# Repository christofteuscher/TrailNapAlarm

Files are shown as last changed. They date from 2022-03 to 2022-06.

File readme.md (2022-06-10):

# Trail Nap Alarm
## Overview
Abstract block diagram
### Introduction and problem statement:
Ultra marathon runners, i.e., runners who run distances longer than a marathon, often do “trail naps,” i.e., they simply lay down on the trail and power nap for 5-10min. When it’s cold, one wakes up after a short period of time, but when it’s warm(er), it’s likely that the runner will sleep longerthan they want. Setting an alarm is tedious, time-consuming, and the alarm may not be heard. Also,sometimes it takes a few minutes to fall asleep, so estimating the wake-up time is hard and the resulting sleep time is rarely ideal.
The goal of this project is to build a device that monitors a runner’s sleep and wakes them up aftersleep stage N1, before they fall into a REM sleep pattern. Non-REM sleep has 3 stages ([Source:](https://www.uofmhealth.org/health-library/hw48331)):
* **Stage** N1 occurs right after you fall asleep and is very short (usually less than 10 minutes).It involves light sleep from which you can be awakened easily.
* **Stage N2** lasts from about 30 to 60 minutes. During this stage, your muscles become more relaxed and you may begin to have slow-wave (delta) brain activity.
* **Stage N3** is deep sleep and lasts about 20 to 40 minutes. During this stage, delta brain activity increases and a person may have some body movements. It is very hard to wake up someone in stage N3.

### Specific project goals
1. Build a sensor system that allows to detect the different sleep patterns. The sensor system needs to be small, simple, non-invasive, and ultra-low power. E.g., an armband, electrodes embedded in a hat, etc.
2. Build a system that reliably wakes up a person. E.g., a combination of sound, vibration, etc. That part must also be small, simple, non-invasive, and ultra-low power.
3. An integration of these two sub-components into a fully functional system. Cables should be avoided. If communication between sub-systems is necessary, that should rely on Bluetooth or other protocols.
4. The system must be battery-powered. The batteries should last for at least 3 days (72 hours). The batteries should be rechargeable with a USB cable.
5. The overall system must be small, non-invasive, light, water-proof, easy to use, and have no on-off or other switches.

## Project status
This project is unfinished and serves only as a proof-of-concept. The intention is for the final product to be as passively-operational as possible - meaning that all the user has to do is turn it on and wear it during a nap, then turn it off when they are woken up. For further development, please refer to the [documentation in the wiki for this repository](https://github.com/cteusche/TrailNapAlarm/wiki).

To start developing this project:
1. Clone this repository
2. Install [conda mini-forge](https://github.com/conda-forge/miniforge) package handler.
3. In the terminal, go to the home directory of this repo and run the command 
   
   `conda env create -f environment.yml` 
   
   to set up a new conda environment and install the required python libraries into it.

## Directory structure
* [src](https://github.com/cteusche/TrailNapAlarm/tree/main/src)
    * Source code files belong here
* [tools](https://github.com/cteusche/TrailNapAlarm/tree/main/tools)
    * Tools like Makefile and other scripts belong here
* [docs](https://github.com/cteusche/TrailNapAlarm/tree/main/docs)
    * Documentation files belong here
* [dep](https://github.com/cteusche/TrailNapAlarm/tree/main/dep)
    * Dependencies belong here
* [res](https://github.com/cteusche/TrailNapAlarm/tree/main/res)
    * Resource files belong here

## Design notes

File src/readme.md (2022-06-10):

# Description of program files and their context

Core application function is handled by record.py, analysis.py, and buzzer.py.

Python programs are connected via piping to form the core function.

## record.py

Sample and record brainwave data from ADC. Send data to analysis.py for processing. 

```
Usage: record.py [options]

Record sampled EEG data.

Options:
  -h, --help            show this help message and exit
  --wav                 Save epoch as wav file format.
  --csv                 Save epoch as csv file format. (Not Implemented)
  -s EPOCH_SECONDS, --seconds=EPOCH_SECONDS
                        Number of seconds in each epoch.
  -n NUM_EPOCHS, --num_epochs=NUM_EPOCHS
                        Number of epochs to record.
  -v, --view_samples    Display samples at a reduced rate.
```

Command line options exist for testing and debug. We can set epoch size and the number of epochs to record as well as enable viewing scaled sample values directly from command line.

We usually run with `python3 record.py --wav` and pipe output into the `analysis.py` program for processing.

### ADS1115 Configuration

We configure the ADS1115 to read data in the ±1.024 range. We sample data on the AIN2 pin with AIN3 as the zero reference. The configuration string `0b0_011_011_0_101_00000` is sent over I2C to initialize the continuous sampling. The device is configured to send interrupts when the data is ready.

We setup an interrupt service routine to watch for interrupts on the device.

### Checking the Timing of the ADS1115

Readings were taking a longer then expected time for the configured Samples Per Second (SPS) value. Used the oscilloscope to check the timing of the interrupt pulses. We noticed the rate was not correct. Checked generated rate by scope for 250 SPS and measured 243 Hz. Added code to time elapsed time over the span of a 30s epoch. We have the optoion to correct the recored rate based on the first measured samplerate.

*Timing is still a bit off. Perhaps we look into device driven data rate again.*

## analysis.py

This program implements the YASA sleep staging algorithm and determines when to wake the user based on a specified N2 epoch count threshold. It takes a file path as a command line argument and concatenates it to an ongoing array of the current sleep session's EEG time series data, with a corresponding sample rate. Once the array of data has surpassed the minimum analysis duration of 5 minutes, as well as the minimum sleep duration specified, it creates a SleepStaging instance to determine the predicted sleep stages for each epoch of recorded data. It repeats this each time it recieves a new filepath, which is every 30 seconds. Once the previous conditions are met, and an N2 threshold is surpassed or the maximum sleep duration has passed, the program activates the alarm system.

User preferences are defined at the top of this file:

minNapMinutes: integer, the minimum number of minutes that the nap should last. The program will not start counting N2 stages detected before this time. This is especially helpful at the start of the program, when predicted sleep stages can be less reliable, so we don't accidentally wake the user too soon.

maxNapMinutes: integer, the maximum number of minutes that the nap should last. As a default, in case the N2 threshold count is not met, the program will wake the user after this number of minutes has elapsed.

minN2epochs: integer, the N2 threshold count. The program will wake the user after this many epochs (30 second segments) have been predicted as stage N2 sleep.

## buzzer.py

This module contains code to play notificaitons on the buzzer. Commands are piped in line by line and the program reacts. Internally the program uses signals to time tones.

- 'READY' plays when the device is connected and ready to start recording.
- 'WAKEUP' command plays the alarm tone to awake the user.
- 'STOP' stops any playing sounds.
- 'TEST' plays a test signal to test the range of values.

The program watches carefully for signals to stop playing a sound if anything goes wrong or the program is stopped.

## buildRaw.py

This module contains definitions for functions which translate different data formats into the MNE "raw" object type. The YASA SleepStaging class takes a raw object type. The current formats are .npz, .wav, and array with a corresponding sample rate.

buildRawFromNpz(fs, filepath)

    fs:         integer, sample rate
    filepath:   string, path to the file

buildRawFromWav(filepath)

    filepath:   string, path to the file

buildRawFromArray(fs, array)

    fs:         integer, sample rate
    filepath:   string, path to the file

## dataSetup.py

This program is used entirely for testing and development, and is not implemented in the functioning of the device itself. It was written as a sandboxing tool for reading different recording file times, from various datasets and devices, and cutting them up into 30 second .wav files to simulate data being fed to analysis.py

## read.py

A test file used in conjunction with send.py. This program is piped a command and a file name from send.py and follows the command sent.

## send.py

A test file that creates a list of files in a directory, then sends the path name to analysis.py one at a time to test the functioning of piping recording file names to the analysis program.

## test.py

Uses functions defined in testPlots.py to make certain plots and analyses on datasets gathered by the team. Given a directory with a .wav file of sleep data, it returns the predicted sleep stages of that dataset and makes a plot of a specified epoch with any detected sleep spindles highlighted.

## testPlots.py

This module contains definitions for functions used in test.py.

spindlePlot(fs,indata,epochNum,title,window)

    fs:         integer, specifies the sample rate of the data
    indata:     array of real-valued data to be plotted
    epochNum:   integer, which 30 second segment to display
    title:      string, the predicted sleep stage of the plotted epoch
    window:     integer, length in samples of the moving average window to smooth plot output (doesn't affect analysis)

The other functions in testPlots.py weren't used in this project.

## test_buzzer.py

This module contains initial code to verify that the buzzer is working.

## test_interrupt.py

This module contains initial code to verify interrupt processing is working.

## Unused/Retired Files

We archive unused files in the `_unused` folder.

-  `btnWake.py` Poll for a change on an analog read pin as a makeshift interrupt. Used for initial i2c bringup. Owner: Michael
- `collectData_0.1.py` Initial pass at i2c code without interurpt. Timing was a problem even here. Owner: Michael
- `collectData_0.2.py` Version 2 of i2c code. This eventually formed into `record.py`. Owner: Julia
- `every.py` Attempt at abstracting away precise timing with python. Retired for interrupt based timing from ADC source. Could be useful for future work. Owner: Julia
- `pollData.py` Initial implementation of i2c code. Owner: Michael
- `pollStart.py` Initial implementation of i2c code. Owner: Michael

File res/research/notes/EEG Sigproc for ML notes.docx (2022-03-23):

Also, there are other rhythms introduced by researchers such as:

e) Phi (φ) rhythm (less than 4 Hz) occurring within two seconds of eye closure. The phi rhythm was introduced by Daly [3].

f) The kappa (κ) rhythm, which is an anterior temporal alpha-like rhythm and it is believed to be the result of discrete lateral oscillations of the eyeballs and is considered to be an artefact signal.

g) The sleep spindles (also called sigma [σ] activity) within the 11–15 Hz frequency range.

h) Tau (τ) rhythm which represents the alpha activity in the temporal region.

i) Eyelid flutter with closed eyes which gives rise to frontal artefacts in the alpha band.

j) Chi rhythm is a mu-like activity believed to be a specific rolandic pattern of 11–17 Hz.

This wave has been observed during the course of Hatha Yoga exercises [8].

k) Lambda (λ) waves are most prominent in waking patients, although they are not very common. They are sharp transients occurring over the occipital region of the head of walking subjects during visual exploration. They are positive and time-locked to sac-

cadic eye movement with varying amplitude, generally below 90 μV [9].

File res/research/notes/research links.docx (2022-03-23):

### Existing research on EEG data

You might have to be logged in through the PSU library portal to access some of the IEEE datasets.

Basic introduction to EEGs and brainwaves

https://www.medicine.mcgill.ca/physio/vlab/biomed_signals/eeg_n.htm

Sleep Stages and Scoring Technique

http://www.fmed.edu.uy/sites/www.labsueno.fmed.edu.uy/files/9.Diagnostico-polisomnogr%C3%A1fico.pdf

Normal Sleep EEG

https://emedicine.medscape.com/article/1140322-overview#a1

Visualization of Whole-Night Sleep EEG From 2-Channel Mobile Recording Device Reveals Distinct Deep Sleep Stages with Differential Electrodermal Activity

https://www.frontiersin.org/articles/10.3389/fnhum.2016.00605/full

Analysis of Multichannel EEG Patterns During Human Sleep: A Novel Approach

https://www.frontiersin.org/articles/10.3389/fnhum.2018.00121/full

Electroencephalography: An Introductory Text and Atlas of Normal and Abnormal Findings in Adults, Children, and Infants

https://www.ncbi.nlm.nih.gov/books/NBK390354/pdf/Bookshelf_NBK390354.pdf

Comparison of Smoothing Filters in Analysis of EEG Data for the Medical Diagnostics Purposes

https://www.ncbi.nlm.nih.gov/pmc/articles/PMC7038754/

EEG-Datasets

https://github.com/meagmohit/EEG-Datasets

DATASETS FOR "GRAPH ANALYSIS OF SINGLE-CHANNEL SLEEP STAGE EEG WITH DIFFERENT ELECTRODE PLACEMENTS"

https://ieee-dataport.org/documents/datasets-graph-analysis-single-channel-sleep-stage-eeg-different-electrode-placements

ACTIVITIES OF DAILY LIVINGS USING A PORTABLE EEG HEADSET

https://ieee-dataport.org/open-access/activities-daily-livings-using-portable-eeg-headset

DIY EEG (and ECG) Circuit

https://www.instructables.com/DIY-EEG-and-ECG-Circuit/

Final Project: DIY EEG EEG: Cheap and Small Fall 2015

http://fab.cba.mit.edu/classes/863.15/section.Harvard/people/Ricker/htm/Final_Project.html

She links to this:

Homebrew Do-it-yourself EEG, EKG, and EMG

https://sites.google.com/site/chipstein/home-page

(good idea… but some broken links)

Make an EEG Beanie That Reads Your Mind

https://makezine.com/projects/mind-reading-beanie/

The Introductory Guide to EEG

(Electroencephalography)

https://www.emotiv.com/eeg-guide/

(interesting idea using the ear to hold electrodes)

Unobtrusive ambulatory EEG using a smartphone and flexible printed electrodes around the ear

https://www.nature.com/articles/srep16743

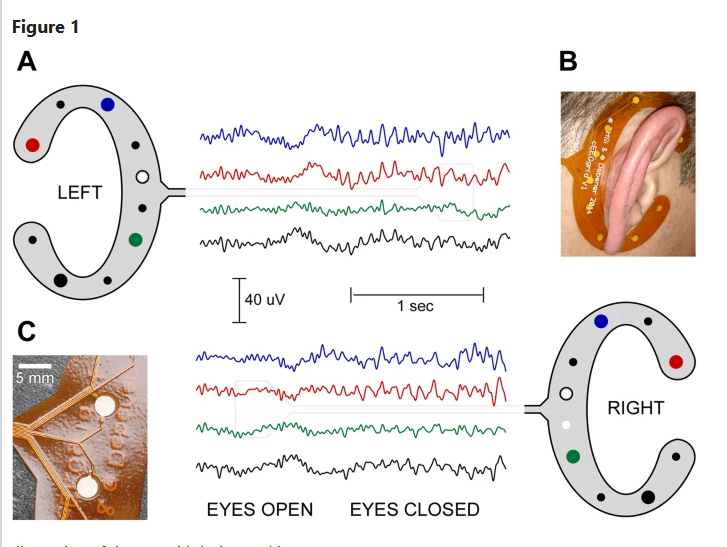
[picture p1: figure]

(I like this one… But there are broken links. Maybe it's a dead project)

Welcome to the OpenEEG project

http://openeeg.sourceforge.net/doc/index.html

EEG probe electrode amplifier design

https://www.researchgate.net/publication/50398093_Portable_cost-effective_EEG_data_acquisition_system

https://www.sleepfoundation.org/stages-of-sleep

TinySleepNet - open source deep learning model for sleep scoring (python)

https://github.com/akaraspt/tinysleepnet

https://ieeexplore.ieee.org/document/9176741

Using Two EEG electrodes on forehead

https://pubmed.ncbi.nlm.nih.gov/24313630/

EEG Montage configurations (not entirely applicable but useful knowledge)
https://www.learningeeg.com/montages-and-technical-components

AASM Recommendations for EEG Electrode Placement in Polysomnography: Impact on Sleep and Cortical Arousal Scoring
https://academic.oup.com/sleep/article/34/1/73/2433800?login=false

Main features of the EEG amplifier explained

https://www.bitbrain.com/blog/eeg-amplifier

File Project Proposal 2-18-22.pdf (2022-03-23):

# AUTOMATIC SLEEP MONITOR AND TRAIL NAP ALARM

Team 23:
Nick Porter, Luke Hoskam, Dang Nguyen, Julia Filipchuk, Michael Weston Industry Sponsor: Dr. Christof Teuscher Faculty Advisor: Dr. Donald Duncan

## Executive Summary

The purpose of this project is to design and prototype a wearable device which can monitor the wearer’s stages of sleep and wake them from a short (10-20 minute) nap after N1 stage sleep, but before REM. This requirement puts the optimal time of awakening during the N2 stage of sleep.
The device fits within a lightweight and unobtrusive headband that passively monitors a person’s heart-rate and EEG while worn. It works without user interaction. The device continuously monitors via two electrode probes within the headband on the forehead at locations FP1 and FP2 [1] and a reference probe connected to the earlobe. From this location, both heart rate and EEG signals can be detected using the same probes.
These signals will be passed to a microcontroller within the headband to process and detect when the user is resting, and what stage of sleep they are currently in. It will allow the user to sleep for roughly 15 minutes (starting from N1 stage detection, but including at least 3 minutes of stage N2), but no longer than 30 minutes. The user will then be awoken using a small vibrating motor and sound. We explain the reasoning behind these choices in the following sections.

## Background

The design of this device will rely on existing research in biometrics, automated sleep research, and digital signal processing (DSP) libraries for small embedded devices.
Sites FP1 and FP2 were chosen since they are optimal for detecting heart rate, as well as sleep spindles and k-complexes during N2 stage [1].
Research in sleep shows that 20 minute naps are more effective for performance than longer naps, and that sleep inertia occurs after 30 minutes. It also shows that stage 2 has a significant effect on restorative effects, and that at least 3 minutes of stage 2 sleep can be beneficial to performance recovery [2].
NREM sleep is divided into 4 sleep stages, which progress from drowsiness into deep sleep before switching into REM sleep. These stages are accompanied by a series of frequency changes through dominant Alpha (8 - 12 Hz), Beta (12 - 38Hz), Theta (3 - 8Hz), and Delta (0.5 -3Hz) waves. Stage 1 NREM sleep is best characterized by being easy to wake from and a reduction of Alpha waves in adults. As drowsiness deepens, the slow wave activity grows. At the transition between stages 1 and 2, the phenomena of vertex waves and sleep spindles will occur. At stage 2, eye movement will cease, low frequencies will dominate, and K-complex components will be present. Further stages 3 and 4 will be denoted by the increasing presence of Delta waves.
This project focuses on using EEG signals for sleep stage detection, but there are new developments in using only heart-rate monitoring for this purpose. One such study provides a method for sleep stage detection using just a heart rate signal, with a theoretical recognition rate for N2 stage of 90% [3]. We are not pursuing this method since there are less software resources available. Heart rate nonetheless is still useful for indicating the initial transition from active movement to a resting state.

## Product Design Specification

### Concept of operations / User stories

Long distance trail runners have to fit short periods of rest in a multiple-day endurance race. Sleep is critical to recovery for runners who compete in races that last for days. In order to get enough sleep and not lose your position in a race, competitors have to time their sleep to the minute. They often have to take short (10-20 minute) naps along the trail. Brief naps have a tendency to leave a person groggy, especially if they are awoken during certain sleep stages, and every person’s sleep cycles are slightly different.
The Trail Nap sleep alarm addresses this issue by monitoring a person’s biometrics and detecting when they are in different stages of sleep in order to awaken the wearer after a duration that leaves them less groggy than if they hadn’t used this device. That duration depends on how quickly the user falls asleep, and how much time they spend on each sleep stage. The device works passively, so the user does not have to take the time to set an alarm, or even engage it when they decide to stop for a nap.

### Stakeholders

Dr. Christof Teuscher is a professor at PSU, director of the Teuscher Lab, and an avid trail runner. He is the industry sponsor for this project, and created the initial project proposal we are basing this project on. The team itself is also a stakeholder in this project, as the main researchers and developers for the final prototype.
We specifically designed this system for endurance trail runners. It will be used by our industry sponsor, but we will also make the designs open-source and available to anyone who wishes to build it using our documentation. There are no current plans for commercialization.

### Requirements

As quoted from our industry sponsor’s project proposal: “The goal of this project is to build a device that monitors a runner’s sleep and wakes them up after sleep stage N1, before they fall into a REM sleep pattern.” This goal, along with the expectation that a nap will be 15-20 minutes (and no longer than 30 minutes) means that the user will reliably be woken up during stage 2 sleep (N2).

Further requirements include:
- Must detect different sleep stages.
- Must reliably wake person after 3 minutes of stage 2 (N2) sleep, but before 30 minutes of sleep
- Must be small, non-invasive, light, easy to use
- Should have no on-off or other switches
- We might have a power switch to shut off when not worn
- Should be water-proof
- Must be “ultra-low power”
- Must be battery powered
- Batteries should last 3 days
- Should be rechargeable over USB
- May be two devices which connect wirelessly

### Specifications

- PocketBeagle with two 3000mAh LiPo batteries will yield ~1200 hours in idle and ~24 hours stressed.
- PocketBeagle integrated LiPo battery regulation
- Target weight limit: ~4 ounces. No more than 0.5 lbs.

### Deliverables

- A functional prototype
- Code (on github), nicely documented
- Project proposal
- Weekly Progress Reports to our faculty advisor, as well as to our industry sponsor if they desire.
- Final report
- ECE capstone session poster
- Any other documentation or activities (presentations) the faculty advisor requires
- Electrical CAD: Schematics and board layouts, including output files (Gerbers, PDFs, etc)
- Mechanical CAD: enclosures, mechanisms, including output files (STLs, PDFs, etc)
- Bill of materials and pricing
- Short user manuals documenting how to use the device and software
- Version control, including checked in previous revisions of the design (via git repo)

### Initial product designs

Hardware Architecture

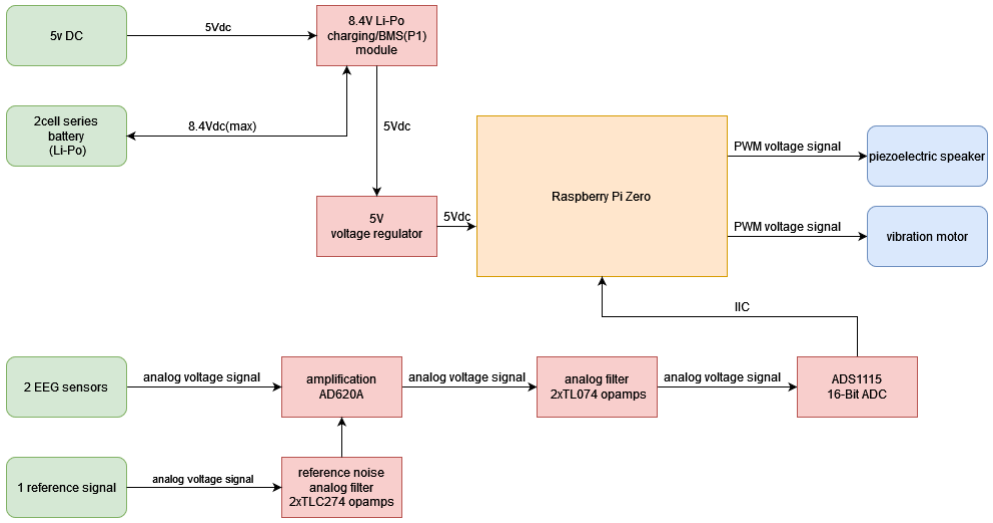
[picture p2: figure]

Fig. 1: L1 diagram of Nap Monitor (the Pi-zero has been replaced with a PocketBeagle)

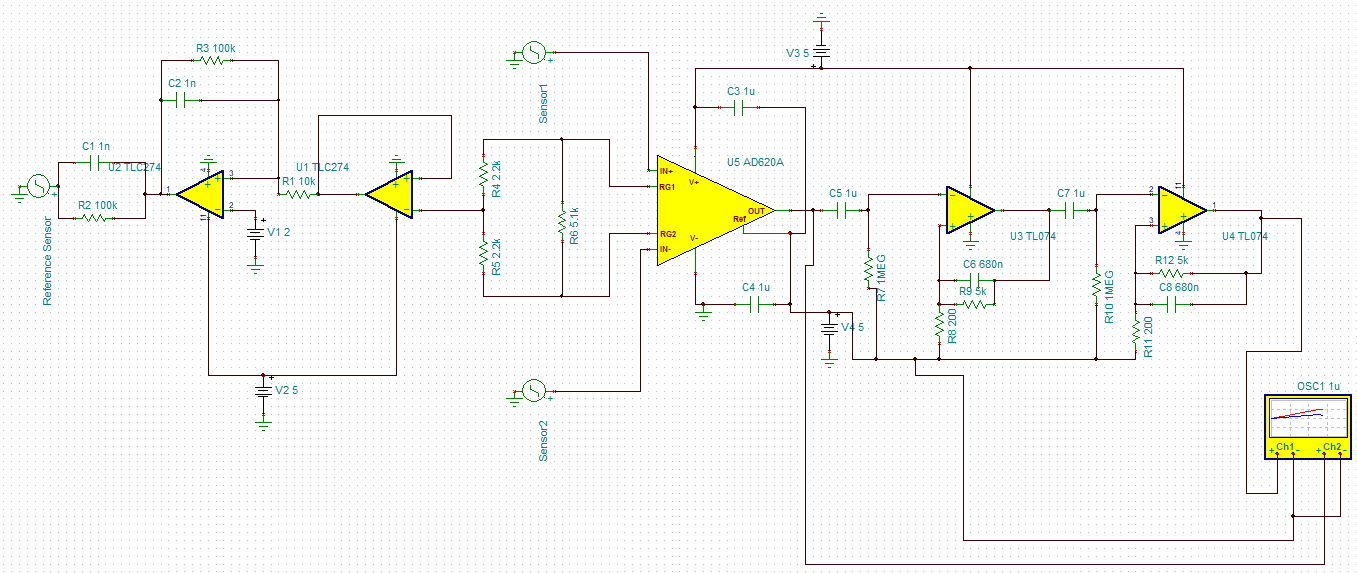
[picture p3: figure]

Fig. 2: Circuit design for a dual EEG probe amplification and analog LPF based on the paper, Portable cost-effective EEG data acquisition system [4]

The above amplification system allows for common voltages between the two electrodes to be canceled out, thus reducing the noise levels from movement. The PocketBeagle is powered at 5v and can provide power to the amplification circuit. The design of the amplification system includes a method of using a virtual ground for +/- rails.

Microcontroller: Pi-Zero PocketBeagle
- Balancing low power and size with processing capacity
- Cheap, accessible
- Easily configurable with peripheral devices

The basic signal chain will go like this: low-voltage noisy signals are amplified, then some rough analog low-pass filtering will occur to pass the analog signal into the ADS1115 ADC. The digital signal will then be passed to the processor via I

2C.

Software Architecture
We intend to use the Python MNE library (https://mne.tools) for developing digital filters and event detection methods. This library, along with the available resources for using Python on a microcontroller, should be enough to allow us to begin software development using the hardware design described in this document.

The signal chain described above will result in a digital time series of EEG data, with a bandwidth of 0.16-47 Hz [4]. From this, the time series is portioned into 20 second segments, called epochs, resulting in a 20 second delay between receiving the first bit of the epoch and any potential output action taken by the processor. Digital filtering is then applied to the epoch using the MNE library to reduce noise from muscle movement, signal drift, EM noise from the device itself (power switching), and heartbeat signals. Further data cleaning might be needed, such as dropping transient artifacts, or discontinuous anomalies.

Once the input epoch is cleaned, we can use impulse convolution methods such as YASA (Yet Another Spindle Algorithm) [5] to detect frequency characteristics, as well as sleep symbols, such as sleep spindles and k-complexes. K-complex detection will play a prominent role in N2 detection. Digital FIR filtering should work for this, since we are less concerned with computation time, and more concerned with retaining an accurate shape of the EEG profile.

The Python environment is a good tool for prototyping digital signal processing methods. Although we might specify a specific method in this proposal, we will have to modify our designs to accommodate the output we will get from our successive hardware prototypes. Python is widely used in the EEG signal processing community and allows us to quickly use existing EEG libraries and datasets to develop digital filter designs and sleep stage detection algorithms.

It is possible we will run into memory and processing constraints using the MNE library directly on the microcontroller. In that case, we will use those tools to pre-process static arrays of impulse responses and wavelets to be convolved in real time and used conditionally on the device processor. This method may not be as robust, but it will be much less computationally expensive.

Sleep studies in the past have required a technician to score EEG data to mark when specific sleep stages occur in the analyzed time series. We plan to use a deep learning algorithm called TinySleepNet [6] to score our EEG data for testing and verification (The paper cited for this references DeepSleepNet, which has since been updated by the creators to be much smaller and more efficient and renamed TinySleepNet, https://github.com/akaraspt/tinysleepnet).

Data Flow:
The digital EEG data stream from the ADC is read by the processor, which creates a 20 second ‘epoch’. Digital filtering is then applied to the epoch to reduce noise and get rid of digital artifacts. Heart rate monitoring is used to determine when the user has begun to transition from running to resting. Wavelet convolution and threshold detection are applied to the epoch to detect signs of Stage 2 sleep, such as low frequency brainwaves, k-complexes, and sleep spindles. This process repeats for each epoch, every 20 seconds. Once three minutes of stage 2 sleep has passed, the processor will trigger the alarm system to gently wake the user.

User Interface / experience
The product is used in the following way: the user puts on the headband before the race and wears it throughout. The device monitors the user's heart-rate passively via the two electrodes. At some point, the wearer stops to rest. The headband detects that the user is no longer running and is resting at which point the processor begins to process the electrode input as EEG signals instead of heart rate. As the user lies down and naps, the device detects the initial stages of sleep. Once the device has recorded at least 3 minutes of N2 sleep (with a total duration since first signs of N1 stage no longer than 30 minutes), it awakens the user with an alarm sound and a gentle vibration. The device detects that the user has awoken and shuts off the alarm, returning to heart-rate monitoring as the user returns to running, now refreshed.

Backup plans
- If the device becomes too large for the headband, we plan on separating it into two devices: a control device worn on a clip at the hip and the sensors in the headband. The two devices will communicate wirelessly through bluetooth.
- If we cannot get clean enough EEG signals from our two probes, we will use the same hardware to attempt sleep stage detection using heart rate signals and the method described in the paper Sleep stage detection using only heart rate [3].

### Verification plans

- We plan to use the Deep Learning system TinySleepNet [6] to aid us in sleep scoring for testing purposes. This will verify if our methods are working as intended. This will not be implemented onto the device, but only used externally for testing purposes.

## Project Management Plan

### Timeline, with milestones

[Gantt chart] (https://docs.google.com/spreadsheets/d/1NYgW1EJNdBPd6kXo1-JnD-HVDwI2NsNn/edit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) included at the end of this document.

Milestones:

- Initial design parts ordered and received
- First DSP prototype working
- First hardware prototype getting usable EEG signals
- Tested 1st DSP prototype with 1st hardware prototype
- Successful real-time sleep stage detection
- 1st wearable headband prototype with successful sleep stage detection
- Fully working prototype that meets all primary “must” requirements

### Budget and Resources

The preliminary BoM for our initial prototype is included at the end of this document. The two electrodes and reference voltage clip are not included yet, since we are having difficulty narrowing down the many choices. The price for the combination of these 3 additional components will likely be around $60.
(Initial prototype parts have been ordered, with price under $100 as of 2-18-22)

### IP discussion

This project will be licensed under the GNU General Public License. The TinySleepNet (https://github.com/akaraspt/tinysleepnet) project is under the Apache 2.0 license for academic purposes.

### Team and development process

Team members and areas of focus:
- Nick Porter - Biometrics research, DSP, documentation, communications point person
- Luke Hoskam - research components, prototyping hardware
- Dang Nguyen - hardware, prototyping
- Julia Filipchuk - Software/Firmware programing, Scrum Master
- Michael Weston - Backup plans, Gantt chart, research components and order, organization of drive folder

We plan on using a Trello for sprint objectives, as well as the Scrum method.

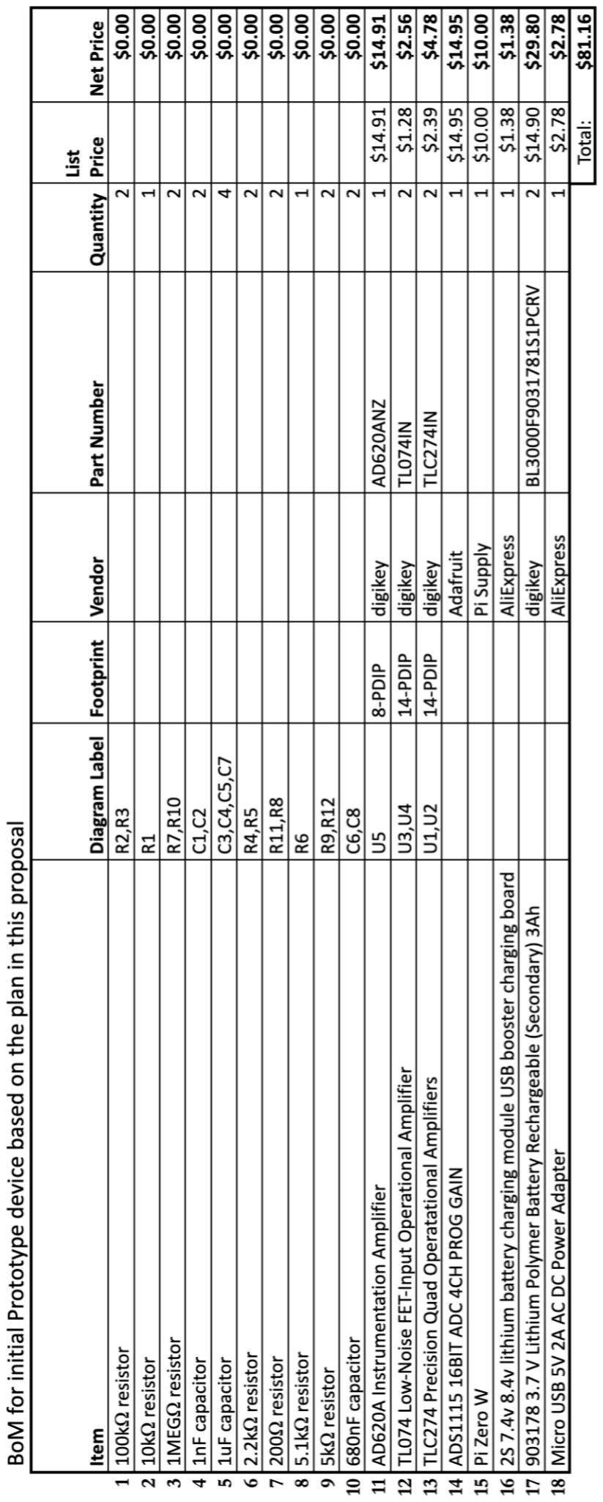
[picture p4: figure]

# References

[1] Malhotra, Raman K. and Alon Y. Avidan. “Chapter 3 – Sleep Stages and Scoring Technique.” (2014).
[2] Hayashi M, Motoyoshi N, Hori T. Recuperative power of a short daytime nap with or without stage 2 sleep. Sleep. 2005 Jul;28(7):829-36. PMID: 16124661.
[3] Mitsukura Y, Fukunaga K, Yasui M, Mimura M. Sleep stage detection using only heart rate. Health Informatics J. 2020 Mar;26(1):376-387. doi: 10.1177/1460458219827349. Epub 2019 Feb 19. PMID: 30782049.
[4] Agarwal N, Nagananda MS, Rahman SM, Sengupta A, Santhosh J, Anand S. Portable cost-effective EEG data acquisition system. J Med Eng Technol. 2011 Apr-May;35(3-4):185-90. doi: 10.3109/03091902.2011.560701. Epub 2011 Mar 16. PMID: 21406039.
[5] Raphael Vallat and Matthew P. Walker (2021). A universal, open-source, high-performance tool for automated sleep staging. bioRxiv 2021.05.28.446165; doi: https://doi.org/10.1101/2021.05.28.446165
[6] A. Supratak, H. Dong, C. Wu and Y. Guo, "DeepSleepNet: A Model for Automatic Sleep Stage Scoring Based on Raw Single-Channel EEG," in IEEE Transactions on Neural Systems and Rehabilitation Engineering, vol. 25, no. 11, pp. 1998-2008, Nov. 2017, doi: 10.1109/TNSRE.2017.2721116.
[7] Sanei, Chambers, Jonathon A., & John Wiley & Sons, publisher. (2021). EEG signal processing and machine learning (Second edition.). Wiley.

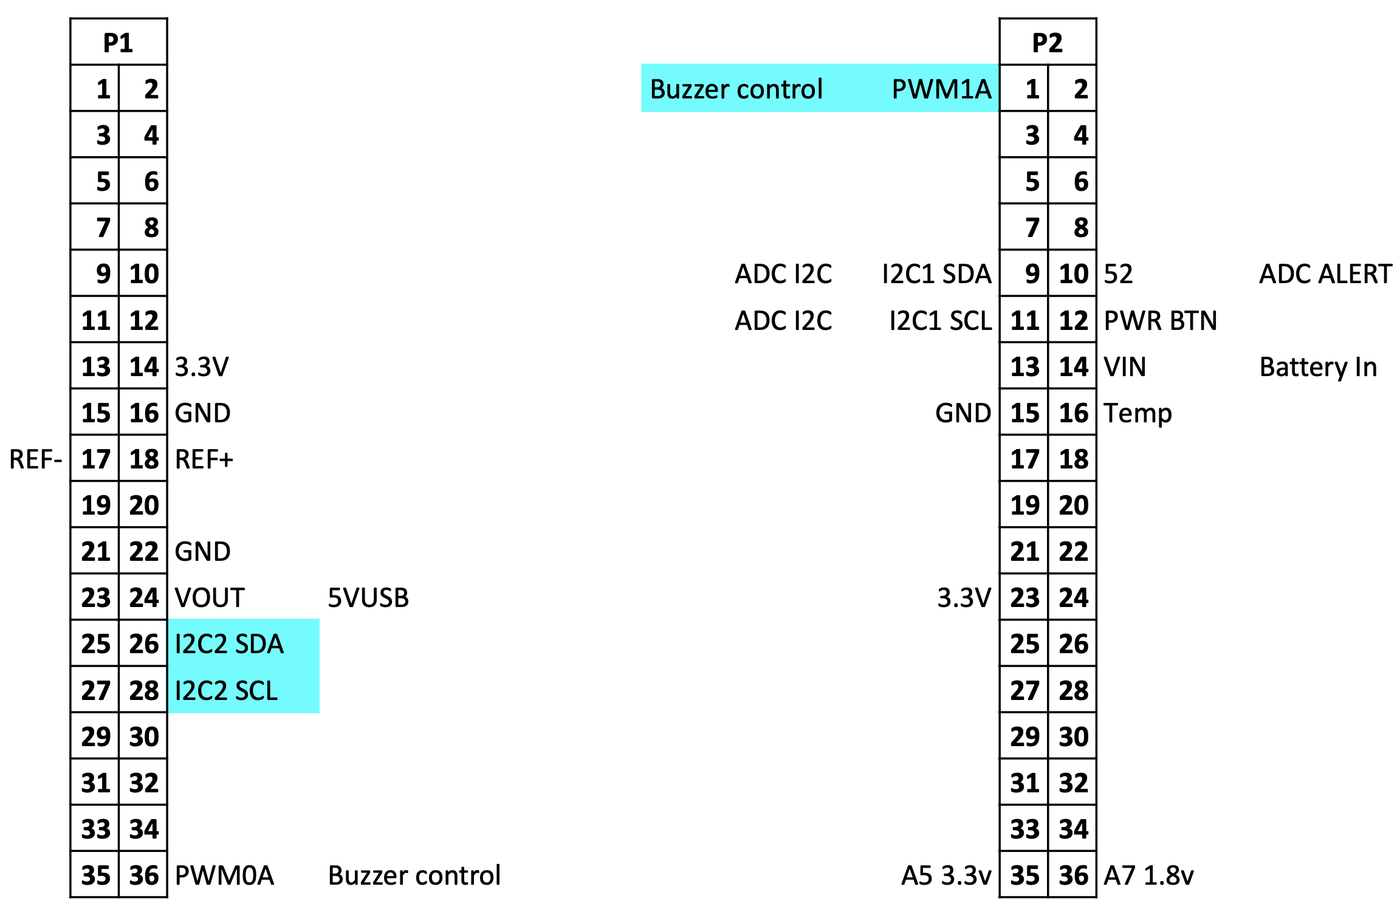
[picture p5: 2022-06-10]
res/figures/docFigs/PB_pinout.png

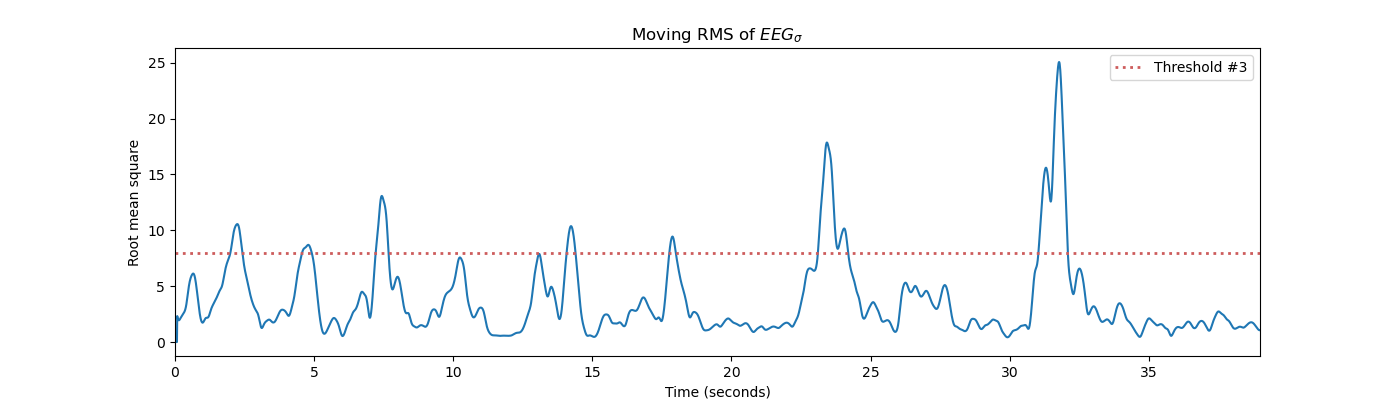
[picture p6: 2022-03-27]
res/figures/exampleYasafigs/Fz_10_movrms.png

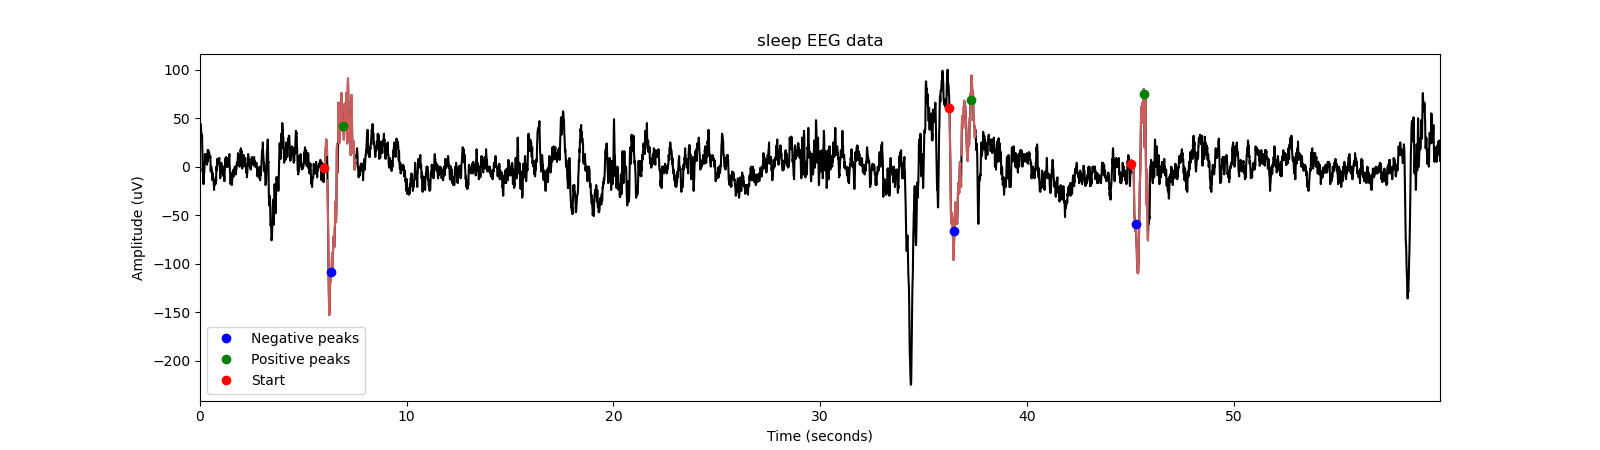
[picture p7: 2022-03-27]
res/figures/exampleYasafigs/Fz_11_slowwaves.png

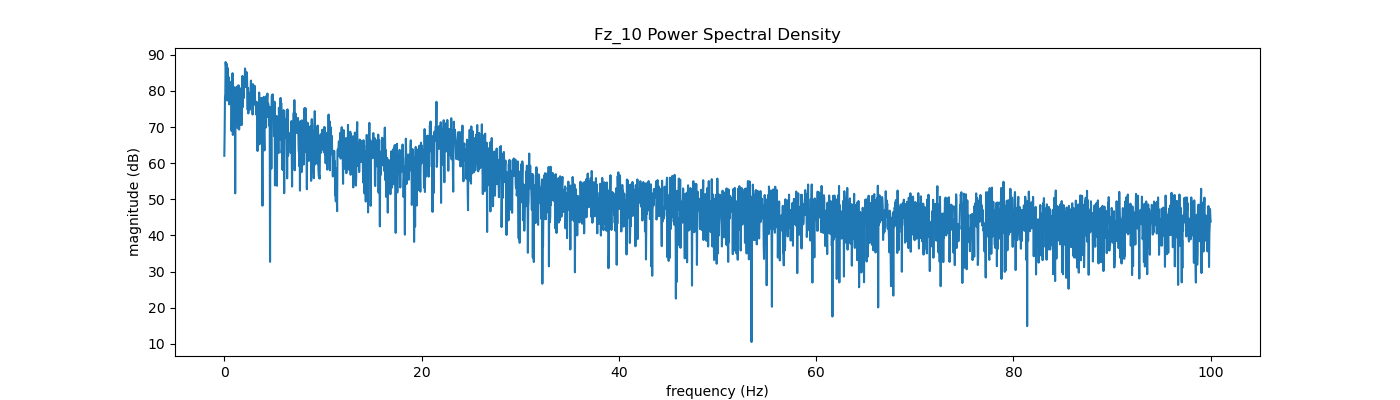
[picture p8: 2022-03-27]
res/figures/exampleYasafigs/Fz_10_psd.png

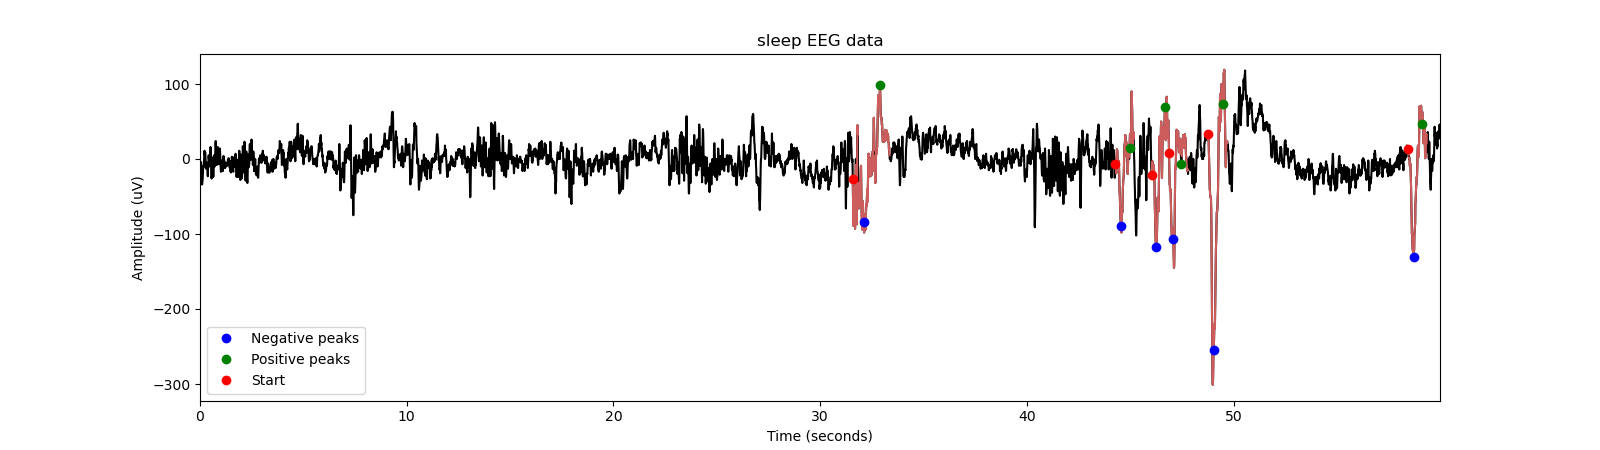
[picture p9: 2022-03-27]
res/figures/exampleYasafigs/Fz_10_slowwaves.png

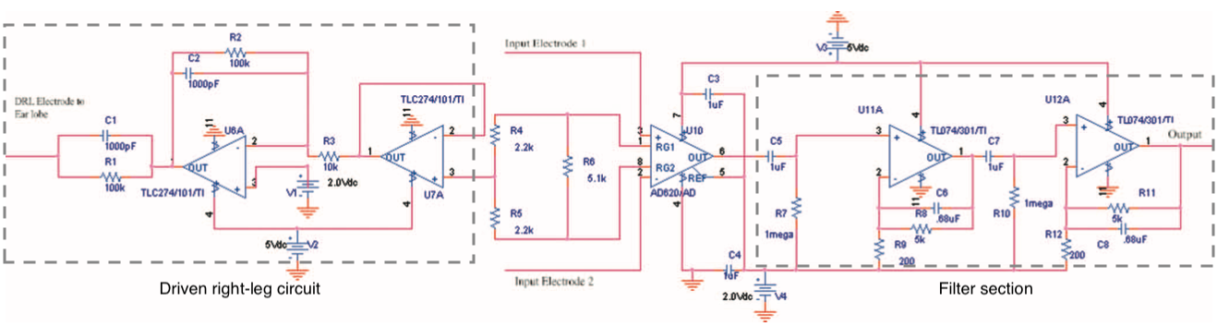
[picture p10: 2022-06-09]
res/figures/docFigs/portableEEG_diag.png

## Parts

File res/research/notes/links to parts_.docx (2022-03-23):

OPAMPS:
https://www.digikey.com/en/products/detail/texas-instruments/TL074IN/378422
https://www.digikey.com/en/products/detail/texas-instruments/TLC274IN/13465085
https://www.digikey.com/en/products/detail/analog-devices-inc/AD620BNZ/699482

ADC:

https://www.digikey.com/en/products/detail/adafruit-industries-llc/1085/5761229

Piezo Speaker:

https://www.digikey.com/en/products/detail/mallory-sonalert-products-inc/PK-11N40PQ/4996072

Vibrator:

https://www.digikey.com/en/products/detail/pololu-corporation/1636/11586848

Charging Module:

Breadboard:

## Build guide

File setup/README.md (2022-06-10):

# Setup PocketBeagle with YASA

Our core processing libraries are [YASA](https://github.com/raphaelvallat/yasa) and [MNE](https://mne.tools/stable/index.html). Setting them up on the device was core to the success of the design. Unfortunatly we have failed at that and were unable to do so. For those that have continued this is a small list of what was tried.

Many dependencies would cause crashes sometime durring the build of the python libraries.

## Trying to bringup YASA on PocketBeagle

conda install numpy scipy matplotlib mne lightgbm`

pip3 install --no-deps yasa
pip3 install --no-deps mne==1.0.3
pip3 install --no-deps pandas==1.4.2 # No version.
pip3 install --no-deps pandas==1.3.5 # Largest version found.
pip3 install pandas==1.3.5 # Has reasonable ammount of things
> builds a numpy which takes a very very long time...

pip3 install sklearn
> Successfully installed joblib-1.1.0 scikit-learn-1.0.2 sklearn-0.0 threadpoolctl-3.1.0

`debian@beaglebone:~/Capstone/setup/TrailNapAlarm$ source ./test`
>``` Length of files: 50
> Traceback (most recent call last):
>   File "src/analysis.py", line 1, in <module>
>     import yasa
>   File "/home/debian/.local/lib/python3.7/site-packages/yasa/__init__.py", line 2, in <module>
>     from .detection import *
>   File "/home/debian/.local/lib/python3.7/site-packages/yasa/detection.py", line 21, in <module>
>     from .numba import _detrend, _rms
>   File "/home/debian/.local/lib/python3.7/site-packages/yasa/numba.py", line 5, in <module>
>     from numba import jit
> ModuleNotFoundError: No module named 'numba'```

`pip3 install numba`
> ```
> Install Failed with missing llvmlite.
> https://llvmlite.readthedocs.io/en/latest/admin-guide/install.html#using-pip```

`sudo apt install python3-llvmlite`
> ```Need to get 36.2 MB of archives.
> After this operation, 211 MB of additional disk space will be used.
> Do you want to continue? [Y/n] Y```

`pip3 install numba`
> `RuntimeError: Could not find a `llvm-config` binary. There are a number of reasons this could occur, please see: https://llvmlite.readthedocs.io/en/latest/admin-guide/install.html#using-pip for help.`

`sudo apt install python3-numb`
> ```Need to get 6,632 kB of archives.
> After this operation, 28.2 MB of additional disk space will be used.
> Do you want to continue? [Y/n] Y```

`source ./test`
> ```Length of files: 50
> /usr/lib/python3/dist-packages/numba/errors.py:104: UserWarning: Insufficiently recent colorama version found. Numba requires colorama >= 0.3.9
>   warnings.warn(msg)
> Traceback (most recent call last):
>   File "src/analysis.py", line 1, in <module>
>     import yasa
>   File "/home/debian/.local/lib/python3.7/site-packages/yasa/__init__.py", line 3, in <module>
>     from .features import *
>   File "/home/debian/.local/lib/python3.7/site-packages/yasa/features.py", line 24, in <module>
>     import antropy as ant
> ModuleNotFoundError: No module named 'antropy'```

`sudo apt install python3-sklearn-lib`
> ```Reading package lists... Done
> Building dependency tree
> Reading state information... Done
> The following additional packages will be installed:
>   libatlas3-base
> The following NEW packages will be installed:
>   libatlas3-base python3-sklearn-lib
> 0 upgraded, 2 newly installed, 0 to remove and 171 not upgraded.
> Need to get 3,665 kB of archives.
> After this operation, 12.9 MB of additional disk space will be used.
> Do you want to continue? [Y/n] Y```

`pip install -U pip`
>  Updated.

`pip install antropy`
> Out of Space.

Resize Main system Partition. Continue Installation.

`pip3 install antropy`

`pip3 install yasa`
> Installed and good.

`souce ./test`
> ```source ./test
> Length of files: 50
> /usr/lib/python3/dist-packages/numba/errors.py:104: UserWarning: Insufficiently recent colorama version found. Numba requires colorama >= 0.3.9
>   warnings.warn(msg)```

`pip3 show colorama`
> ```Name: colorama
> Version: 0.3.7
> Summary: Cross-platform colored terminal text.
> Home-page: https://github.com/tartley/colorama
> Author: Arnon Yaari
> Author-email: tartley@tartley.com
> License: BSD
> Location: /usr/lib/python3/dist-packages
> Requires:
> Required-by:```

`pip3 install -U colorama>=0.3.9`
> `Installed but did not report anything for some reason.`

`pip3 show colorama`
> ```Name: colorama
> Version: 0.4.4
> Summary: Cross-platform colored terminal text.
> Home-page: https://github.com/tartley/colorama
> Author: Jonathan Hartley
> Author-email: tartley@tartley.com
> License: BSD
> Location: /home/debian/.local/lib/python3.7/site-packages
> Requires:
> Required-by:```

`souce ./test`
> ```Length of files: 50
> Traceback (most recent call last):
>   File "/usr/lib/python3/dist-packages/numba/errors.py", line 617, in new_error_context
>     yield
>   File "/usr/lib/python3/dist-packages/numba/lowering.py", line 259, in lower_block
>     self.lower_inst(inst)
>   File "/usr/lib/python3/dist-packages/numba/lowering.py", line 308, in lower_inst
>     val = self.lower_assign(ty, inst)
>   File "/usr/lib/python3/dist-packages/numba/lowering.py", line 454, in lower_assign
>     return self.lower_expr(ty, value)
>   File "/usr/lib/python3/dist-packages/numba/lowering.py", line 883, in lower_expr
>     res = self.lower_call(resty, expr)
>   File "/usr/lib/python3/dist-packages/numba/lowering.py", line 849, in lower_call
>     res = impl(self.builder, argvals, self.loc)
>   File "/usr/lib/python3/dist-packages/numba/targets/base.py", line 1124, in __call__
>     return self._imp(self._context, builder, self._sig, args, loc=loc)
>   File "/usr/lib/python3/dist-packages/numba/targets/base.py", line 1147, in wrapper
>     return fn(*args, **kwargs)
>   File "/usr/lib/python3/dist-packages/numba/unsafe/ndarray.py", line 32, in codegen
>     res = _empty_nd_impl(context, builder, arrty, shapes)
>   File "/usr/lib/python3/dist-packages/numba/targets/arrayobj.py", line 3167, in _empty_nd_impl
>     arrlen = builder.mul(arrlen, s)
>   File "/usr/lib/python3/dist-packages/llvmlite/ir/builder.py", line 24, in wrapped
>     % (lhs.type, rhs.type))
> ValueError: Operands must be the same type, got (i32, i64)
> 
> During handling of the above exception, another exception occurred:
> 
> Traceback (most recent call last):
>   File "src/analysis.py", line 1, in <module>
>     import yasa
>   File "/home/debian/.local/lib/python3.7/site-packages/yasa/__init__.py", line 3, in <module>
>     from .features import *
>   File "/home/debian/.local/lib/python3.7/site-packages/yasa/features.py", line 24, in <module>
>     import antropy as ant
>   File "/home/debian/.local/lib/python3.7/site-packages/antropy/__init__.py", line 4, in <module>
>     from .fractal import *
>   File "/home/debian/.local/lib/python3.7/site-packages/antropy/fractal.py", line 303, in <module>
>     @jit('f8(f8[:])', nopython=True)
>   File "/usr/lib/python3/dist-packages/numba/decorators.py", line 183, in wrapper
>     disp.compile(sig)
>   File "/usr/lib/python3/dist-packages/numba/compiler_lock.py", line 32, in _acquire_compile_lock
>     return func(*args, **kwargs)
>   File "/usr/lib/python3/dist-packages/numba/dispatcher.py", line 655, in compile
>     cres = self._compiler.compile(args, return_type)
>   File "/usr/lib/python3/dist-packages/numba/dispatcher.py", line 82, in compile
>     pipeline_class=self.pipeline_class)
>   File "/usr/lib/python3/dist-packages/numba/compiler.py", line 926, in compile_extra
>     return pipeline.compile_extra(func)
>   File "/usr/lib/python3/dist-packages/numba/compiler.py", line 374, in compile_extra
>     return self._compile_bytecode()
>   File "/usr/lib/python3/dist-packages/numba/compiler.py", line 857, in _compile_bytecode
>     return self._compile_core()
>   File "/usr/lib/python3/dist-packages/numba/compiler.py", line 844, in _compile_core
>     res = pm.run(self.status)
>   File "/usr/lib/python3/dist-packages/numba/compiler_lock.py", line 32, in _acquire_compile_lock
>     return func(*args, **kwargs)
>   File "/usr/lib/python3/dist-packages/numba/compiler.py", line 255, in run
>     raise patched_exception
>   File "/usr/lib/python3/dist-packages/numba/compiler.py", line 246, in run
>     stage()
>   File "/usr/lib/python3/dist-packages/numba/compiler.py", line 717, in stage_nopython_backend
>     self._backend(lowerfn, objectmode=False)
>   File "/usr/lib/python3/dist-packages/numba/compiler.py", line 666, in _backend
>     lowered = lowerfn()
>   File "/usr/lib/python3/dist-packages/numba/compiler.py", line 653, in backend_nopython_mode
>     self.metadata)
>   File "/usr/lib/python3/dist-packages/numba/compiler.py", line 1048, in native_lowering_stage
>     lower.lower()
>   File "/usr/lib/python3/dist-packages/numba/lowering.py", line 178, in lower
>     self.lower_normal_function(self.fndesc)
>   File "/usr/lib/python3/dist-packages/numba/lowering.py", line 219, in lower_normal_function
>     entry_block_tail = self.lower_function_body()
>   File "/usr/lib/python3/dist-packages/numba/lowering.py", line 244, in lower_function_body
>     self.lower_block(block)
>   File "/usr/lib/python3/dist-packages/numba/lowering.py", line 259, in lower_block
>     self.lower_inst(inst)
>   File "/usr/lib/python3.7/contextlib.py", line 130, in __exit__
>     self.gen.throw(type, value, traceback)
>   File "/usr/lib/python3/dist-packages/numba/errors.py", line 625, in new_error_context
>     six.reraise(type(newerr), newerr, tb)
>   File "/usr/lib/python3/dist-packages/numba/six.py", line 659, in reraise
>     raise value
> numba.errors.LoweringError: Failed in nopython mode pipeline (step: nopython mode backend)
> Operands must be the same type, got (i32, i64)
> 
> File "../.local/lib/python3.7/site-packages/antropy/fractal.py", line 313:
> def _dfa(x):
>     <source elided>
> 
>     for i_n, n in enumerate(nvals):
>     ^
> 
> [1] During: lowering "array.79 = call empty_func.80(size_tuple.78, func=empty_func.80, args=(Var(size_tuple.78, /home/debian/.local/lib/python3.7/site-packages/antropy/fractal.py (313)),), kws=[], vararg=None)" at /home/debian/.local/lib/python3.7/site-packages/antropy/fractal.py (313)```

Something with dependencies could be wrong. Trying to update yasa again.

`pip3 install -U yasa`
> `All checked. Still no luck.`

Trying to use pip3 llvm.

`pip3 install -U llvmlite`
> `Crash.`

Following the llvmlite manual install [guide]().

`sudo apt install libedit-dev`
`sudo apt install llvm-dev`
> `Installed!`

`pip3 install -U llvmlite`
> ```RuntimeError: Building llvmlite requires LLVM 11.x.x, got '7.0.1'. Be sure to set LLVM_CONFIG to the right executable path.
> Read the documentation at http://llvmlite.pydata.org/ for more information about building llvmlite.```

### Build LLVM

Via [guide](https://github.com/llvm/llvm-project/releases/download/llvmorg-11.1.0/llvm-11.1.0.src.tar.xz).
```
mkdir TrailNapAlarm/setup
cd TrailNapAlarm/setup
wget https://github.com/llvm/llvm-project/releases/download/llvmorg-11.1.0/llvm-11.1.0.src.tar.xz
git clone --depth=1 https://github.com/numba/llvmlite
tar xf llvm-11.1.0.src.tar.xz
ls
> llvm-11.1.0.src  llvm-11.1.0.src.tar.xz  llvmlite
cd llvm-11.1.0.src/
# Some Patches skipped... irrellivant or did not work.
patch -p1 -i ../llvmlite/conda-recipes/0001-Revert-Limit-size-of-non-GlobalValue-name.patch
> patching file lib/IR/Value.cpp
> Hunk #1 succeeded at 38 (offset 1 line).
> Hunk #2 succeeded at 290 (offset 56 lines).
> patching file test/Bitcode/value-with-long-name.ll
export PREFIX=../llvm/ CPU_COUNT=1
sudo apt install cmake
rmdir build
bash ../llvmlite/conda-recipes/llvmdev/build.sh
> Really long build...

> Crashed...
```

# To Try....

`LLVM_CONFG=/usr/bin/llvm-config`

### Install Miniconda

armv7l

wget https://repo.anaconda.com/miniconda/Miniconda3-latest-Linux-armv7l.sh
bash Miniconda3-latest-Linux-armv7l.sh

Setup environment for yaml file.

> Unable to install some packages.
> matplotlib not available.
*Removed from list as we will not plot anything here."

> openblas and blas not available.
*Looking for way to install. Should be available on system via apt.

`sudo apt seach blas`
> libblas-dev/oldstable 3.8.0-2 armhf
>   Basic Linear Algebra Subroutines 3, static library
> 
> libblas-test/oldstable 3.8.0-2 armhf
>   Basic Linear Algebra Subroutines 3, testing programs
> 
> libblas3/oldstable,now 3.8.0-2 armhf [installed]
>   Basic Linear Algebra Reference implementations, shared library
> 
> libblis-dev/oldstable 0.5.1-11 armhf
>   BLAS-like Library Instantiation Software Framework

`sudo apt search openblas`
> libopenblas-base/oldstable 0.3.5+ds-3 armhf
>   Optimized BLAS (linear algebra) library (shared library)
> 
> libopenblas-dev/oldstable 0.3.5+ds-3 armhf
>   Optimized BLAS (linear algebra) library (development files)

`sudo apt install libblas3 libblas-dev libopenblas-base libopenblas-dev`
Need to get 4,225 kB of archives.
After this operation, 22.3 MB of additional disk space will be used.

`cat environment.jml`
> name: TrailAlarm
> channels:
>   - conda-forge
> dependencies:
>   - python
>   - pip
>   - numpy
>   - scipy
>   - mne
>   - pip:
>     - yasa

`~/miniconda3/bin/conda install -f environment.yml`
> Error: No packages found in current linux-armv7l channels matching: environment.yml

`~/miniconda3/bin/conda env create -f environment.yml`
> Error: Could not find some dependencies for numpy: blas * openblas

Without conda forge.
> Error: No packages found in current linux-armv7l channels matching: mne

**CONTINUE HERE**

### Install One at at time...
`~/miniconda3/bin/conda create -n Capstone python=3 pip`
>  Ok.

`source ~/miniconda3/bin/activate Capstone`
> Ok

`conda install numpy`
> Error: Could not find some dependencies for numpy: blas * openblas

`conda install -c conda-forge numpy`
> Error: Could not find some dependencies for numpy: blas * openblas

`conda install -c conda-forge numpy --no-deps`
> Error: No packages found in current linux-armv7l channels matching: libblas
> 
> You can search for this package on anaconda.org with
> 
>     anaconda search -t conda libblas
> 
> You may need to install the anaconda-client command line client with
> 
>     conda install anaconda-client

`conda install anaconda-client`
> Ok.
`anaconda search -t conda blas * openblas`
> * import too much...
`anaconda search -t conda openblas`
`anaconda search -t conda openblas | grep linux-armv7l`
> Using binstar api site https://api.anaconda.org
>     microsoft-ell/openblas    |    0.3.6 | conda           | linux-armv7l
>     poppy-project/openblas    |   0.2.15 | conda           | linux-armv7l
>     rpi/openblas              |   0.2.19 | conda           | linux-armv6l, linux-armv7l
>     tballance/openblas        |   0.2.19 | conda           | linux-armv7l

`anaconda search -t conda blas | grep linux-armv7l`
>     rpi/blas                  |      1.1 | conda           | linux-armv7l
>     rpi/openblas              |   0.2.19 | conda           | linux-armv6l, linux-armv7l

Can search for Aarmv7l packages [online](https://anaconda.org/search?q=platform%3Alinux-armv7l) as well. Install them as channel/package specification to conda.
`conda install -c rpi blas`
>   blas:        1.1-openblas
>   libgfortran: 3.0.0-0
>   openblas:    0.2.19-0

`conda install -c  microsoft-ell openblas`
> Good

`conda install -c rpi numpy scipy`
> Hint: the following packages conflict with each other:
>   - scipy
>   - python 3.4*
> 
> Use 'conda info scipy' etc. to see the dependencies for each package.
> 
> Note that the following features are enabled:
>   - blas_openblas

`conda install -c rpi numpy`
> Conflict with python.

`conda install -c rpi python`
> Complete.

`conda install -c rpi numpy`
> Hint: the following packages conflict with each other:
>   - numpy
>   - python 3.4*
> 
> Use 'conda info numpy' etc. to see the dependencies for each package.
> 
> Note that the following features are enabled:
>   - blas_openblas

`conda uninstall python`
`conda install -c rpi python=2 numpy`
`conda install -c rpi pip`
> Environment seems broken... 
`conda remove python pip`
`conda install python=3 pip`
> Yay!
`pip install --updatedupgrade pip`

`pip install mne`
> Start build. Nope

`conda install -c rpi python=3`
> Upgrading some. python 3.6 now.
`conda install -c rpi typing`
> Nope. Conflict. Probably not needed...

`pip install mne`
> Start build. Crashed and hung board.

`source ~/miniconda3/bin/activate TrailAlarm`
`pip install mne --no-deps`
> Installed. May need dependencies later.
`pip install yasa`
> 

**Manual Install of mne and yasa**

`cat environment.yml`
> name: TrailAlarm
> channels:
>   - rpi
> dependencies:
>   - python
>   - pip
>   - numpy
>   - scipy
>   - pip:
>     - mne
>     - yasa
`debian@beaglebone:~/TrailNapAlarm/setup$ ~/miniconda3/bin/conda env create -f environment.yml`
> Lots of wheels downloading.
> Building for a long time. Currently scipy...
> Collecting scipy>=1.1.0 (from mne)
> Collecting matplotlib (from yasa)

Try again. Closed with an accidental Ctrl-c....

Now need to log in and install with pip...

`pip install mne`
> Crashed system again...

**HERE**

`pop install yasa`

*Missing fortran. *
`sudo apt install gfortran`
`pip install mne`
> Crashed system again...

`pip install --no-deps mne`
`pip install yasa'
-- Crashed system on scipy install again.
`pip install --no-deps yasa`

Manually adding dependencies.

`pip install pandas`
> Crashed.

`pip install pandas --no-deps`

**ANOTHER TRY**

`cat environment.yml`
> name: TrailAlarm
> channels:
>   - rpi
> dependencies:
>   - python
>   - pip
>   - numpy
>   - scipy
>   - mne
>   - pip:
>     - yasa

`debian@beaglebone:~/TrailNapAlarm/setup$ ~/miniconda3/bin/conda env create -f environment.yml`
> Error: No packages found in current linux-armv7l channels matching: mne

## Backup SD card

[Guide](http://www.ofitselfso.com/BeagleNotes/CloningABootableBeagleboneBlackSDCard.php) to follow.

# Possibly Useful Possibly Not... Lost track.
## Bringup on BBP

> Traceback (most recent call last):
>   File "src/analysis.py", line 1, in <module>
>     import yasa
>   File "/home/debian/.local/lib/python3.7/site-packages/yasa/__init__.py", line 2, in <module>
>     from .detection import *
>   File "/home/debian/.local/lib/python3.7/site-packages/yasa/detection.py", line 18, in <module>
>     from sklearn.ensemble import IsolationForest
> ModuleNotFoundError: No module named 'sklearn'

pip3 install sklearn

< AAgain....

Installing collected packages: webencodings, wcwidth, Send2Trash, ptyprocess, pickleshare, mistune, littleutils, ipython-genutils, fastjsonschema, backcall, appdirs, zipp, urllib3, traitlets, tornado, tinycss2, soupsieve, pyzmq, pyrsistent, pygments, pycparser, psutil, prompt-toolkit, prometheus-client, pexpect, parso, pandocfilters, nest-asyncio, MarkupSafe, jupyterlab-widgets, jupyterlab-pygments, entrypoints, defusedxml, debugpy, charset-normalizer, certifi, bleach, attrs, terminado, tensorpac, requests, matplotlib-inline, matplotlib, lspopt, jupyter-core, jinja2, jedi, importlib-resources, importlib-metadata, cffi, beautifulsoup4, seaborn, pyriemann, pooch, outdated, jupyter-client, jsonschema, ipython, argon2-cffi-bindings, nbformat, ipykernel, argon2-cffi, nbclient, nbconvert, notebook, widgetsnbextension, ipywidgets
Successfully installed MarkupSafe-2.1.1 Send2Trash-1.8.0 appdirs-1.4.4 argon2-cffi-21.3.0 argon2-cffi-bindings-21.2.0 attrs-21.4.0 backcall-0.2.0 beautifulsoup4-4.11.1 bleach-5.0.0 certifi-2022.5.18.1 cffi-1.15.0 charset-normalizer-2.0.12 debugpy-1.6.0 defusedxml-0.7.1 entrypoints-0.4 fastjsonschema-2.15.3 importlib-metadata-4.11.4 importlib-resources-5.7.1 ipykernel-6.13.0 ipython-7.34.0 ipython-genutils-0.2.0 ipywidgets-7.7.0 jedi-0.18.1 jinja2-3.1.2 jsonschema-4.6.0 jupyter-client-7.3.1 jupyter-core-4.10.0 jupyterlab-pygments-0.2.2 jupyterlab-widgets-1.1.0 littleutils-0.2.2 lspopt-1.1.1 matplotlib-3.5.2 matplotlib-inline-0.1.3 mistune-0.8.4 nbclient-0.6.4 nbconvert-6.5.0 nbformat-5.4.0 nest-asyncio-1.5.5 notebook-6.4.11 outdated-0.2.1 pandocfilters-1.5.0 parso-0.8.3 pexpect-4.8.0 pickleshare-0.7.5 pooch-1.6.0 prometheus-client-0.14.1 prompt-toolkit-3.0.29 psutil-5.9.1 ptyprocess-0.7.0 pycparser-2.21 pygments-2.12.0 pyriemann-0.2.7 pyrsistent-0.18.1 pyzmq-23.1.0 requests-2.27.1 seaborn-0.11.2 soupsieve-2.3.2.post1 tensorpac-0.6.5 terminado-0.15.0 tinycss2-1.1.1 tornado-6.1 traitlets-5.2.2.post1 urllib3-1.26.9 wcwidth-0.2.5 webencodings-0.5.1 widgetsnbextension-3.6.0 zipp-3.8.0

## Other Resources (UNUSED)

### Super quick boot on BB angstrom

[Slides](https://elinux.org/images/b/b3/Elce11_koen.pdf) on how to quick boot BeagleBoard angstrom. Different device. Maybe applicable.

[Thread](https://www.reddit.com/r/embedded/comments/j7cwnn/beaglebone_boottime_reduction/) on a quick boot.

### Custom boot image

[Guide](http://www.blackpeppertech.com/pepper/tech-tree/boot-your-beaglebone-black-in-60-minutes/) to build custom Linux image for BB?.

### Down-clock Pocket Beagle for less power draw

Frequency scaling available through linux file api.

```
cat /sys/devices/system/cpu/cpu0/cpufreq/scaling_available_frequencies
cat /sys/devices/system/cpu/cpu0/cpufreq/scaling_setspeed
```

### Disconnect USB power.

[Guide](https://forum.beagleboard.org/t/turn-usb-power-on-off/30700/4) that reports how to disconnect by write to internal GPIO. May have some issues.

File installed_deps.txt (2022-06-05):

# packages in environment at /opt/homebrew/Caskroom/miniforge/base/envs/sleepMin:
#
# Name                    Version                   Build  Channel
antropy                   0.1.4                    pypi_0    pypi
aom                       3.3.0                h07bb92c_1    conda-forge
appdirs                   1.4.4              pyh9f0ad1d_0    conda-forge
appnope                   0.1.3              pyhd8ed1ab_0    conda-forge
argon2-cffi               21.3.0             pyhd8ed1ab_0    conda-forge
argon2-cffi-bindings      21.2.0          py310hf8d0d8f_2    conda-forge
asttokens                 2.0.5              pyhd8ed1ab_0    conda-forge
attrs                     21.4.0             pyhd8ed1ab_0    conda-forge
backcall                  0.2.0              pyh9f0ad1d_0    conda-forge
backports                 1.0                        py_2    conda-forge
backports.functools_lru_cache 1.6.4              pyhd8ed1ab_0    conda-forge
beautifulsoup4            4.11.1             pyha770c72_0    conda-forge
bleach                    5.0.0              pyhd8ed1ab_0    conda-forge
blosc                     1.21.1               hd414afc_3    conda-forge
brotli                    1.0.9                h1c322ee_7    conda-forge
brotli-bin                1.0.9                h1c322ee_7    conda-forge
brotlipy                  0.7.0           py310hf8d0d8f_1004    conda-forge
brunsli                   0.1                  h9f76cd9_0    conda-forge
bzip2                     1.0.8                h3422bc3_4    conda-forge
c-ares                    1.18.1               h3422bc3_0    conda-forge
c-blosc2                  2.1.1                h10ebec7_2    conda-forge
ca-certificates           2022.5.18.1          h4653dfc_0    conda-forge
cached-property           1.5.2                hd8ed1ab_1    conda-forge
cached_property           1.5.2              pyha770c72_1    conda-forge
certifi                   2022.5.18.1     py310hbe9552e_0    conda-forge
cffi                      1.15.0          py310hf10583b_0    conda-forge
cfitsio                   4.1.0                hd4f5c17_0    conda-forge
charls                    2.3.4                hbdafb3b_0    conda-forge
charset-normalizer        2.0.12             pyhd8ed1ab_0    conda-forge
cloudpickle               2.1.0              pyhd8ed1ab_0    conda-forge
colorama                  0.4.4              pyh9f0ad1d_0    conda-forge
colorspacious             1.1.2              pyh24bf2e0_0    conda-forge
cryptography              37.0.2          py310h94bb23d_0    conda-forge
curl                      7.83.1               h2fcd78c_0    conda-forge
cycler                    0.11.0             pyhd8ed1ab_0    conda-forge
cytoolz                   0.11.2          py310hf8d0d8f_2    conda-forge
darkdetect                0.6.0              pyhd8ed1ab_0    conda-forge
dask-core                 2022.5.2           pyhd8ed1ab_0    conda-forge
debugpy                   1.6.0           py310h1105856_0    conda-forge
decorator                 5.1.1              pyhd8ed1ab_0    conda-forge
defusedxml                0.7.1              pyhd8ed1ab_0    conda-forge
deprecated                1.2.13             pyh6c4a22f_0    conda-forge
dipy                      1.5.0           py310hdaceac9_1    conda-forge
double-conversion         3.2.0                hbdafb3b_0    conda-forge
edflib-python             1.0.6              pyhd8ed1ab_0    conda-forge
eeglabio                  0.0.1.post7        pyhd8ed1ab_0    conda-forge
eigen                     3.4.0                hc021e02_0    conda-forge
entrypoints               0.4                pyhd8ed1ab_0    conda-forge
executing                 0.8.3              pyhd8ed1ab_0    conda-forge
expat                     2.4.8                h6b3803e_0    conda-forge
ffmpeg                    4.4.1                h4556347_5    conda-forge
flit-core                 3.7.1              pyhd8ed1ab_0    conda-forge
fonttools                 4.33.3          py310h02f21da_0    conda-forge
freetype                  2.10.4               h17b34a0_1    conda-forge
fsspec                    2022.5.0           pyhd8ed1ab_0    conda-forge
future                    0.18.2          py310hbe9552e_5    conda-forge
gettext                   0.19.8.1          h049c9fb_1008    conda-forge
giflib                    5.2.1                h27ca646_2    conda-forge
gl2ps                     1.4.2                h17b34a0_0    conda-forge
glew                      2.1.0                h9f76cd9_2    conda-forge
gmp                       6.2.1                h9f76cd9_0    conda-forge
gnutls                    3.7.6                h653af08_2    conda-forge
gst-plugins-base          1.20.2               hbf05cfb_1    conda-forge
gstreamer                 1.20.2               h3d5cedb_1    conda-forge
h5io                      0.1.7              pyh8a188c0_0    conda-forge
h5py                      3.6.0           nompi_py310hb8bbf05_100    conda-forge
hdf4                      4.2.15               h0ef36ac_3    conda-forge
hdf5                      1.12.1          nompi_hf9525e8_104    conda-forge
icu                       70.1                 h6b3803e_0    conda-forge
idna                      3.3                pyhd8ed1ab_0    conda-forge
imagecodecs               2022.2.22       py310h1589e16_5    conda-forge
imageio                   2.19.3             pyhcf75d05_0    conda-forge
imageio-ffmpeg            0.4.7              pyhd8ed1ab_0    conda-forge
importlib-metadata        4.11.4          py310hbe9552e_0    conda-forge
importlib_resources       5.7.1              pyhd8ed1ab_1    conda-forge
ipycanvas                 0.12.0             pyhd8ed1ab_1    conda-forge
ipyevents                 2.0.1              pyhd8ed1ab_0    conda-forge
ipykernel                 6.13.0          py310hc469350_0    conda-forge
ipython                   8.4.0           py310hbe9552e_0    conda-forge
ipython_genutils          0.2.0                      py_1    conda-forge
ipyvtklink                0.2.2              pyhd8ed1ab_0    conda-forge
ipywidgets                7.7.0              pyhd8ed1ab_0    conda-forge
jedi                      0.18.1          py310hbe9552e_1    conda-forge
jinja2                    3.1.2              pyhd8ed1ab_1    conda-forge
joblib                    1.1.0              pyhd8ed1ab_0    conda-forge
jpeg                      9e                   h1c322ee_1    conda-forge
jsoncpp                   1.9.5                hc021e02_1    conda-forge
jsonschema                4.6.0              pyhd8ed1ab_0    conda-forge
jupyter                   1.0.0           py310hbe9552e_7    conda-forge
jupyter_client            7.3.1              pyhd8ed1ab_0    conda-forge
jupyter_console           6.4.3              pyhd8ed1ab_0    conda-forge
jupyter_core              4.10.0          py310hbe9552e_0    conda-forge
jupyterlab_pygments       0.2.2              pyhd8ed1ab_0    conda-forge
jupyterlab_widgets        1.1.0              pyhd8ed1ab_0    conda-forge
jxrlib                    1.1                  h27ca646_2    conda-forge
kiwisolver                1.4.2           py310hea002bf_1    conda-forge
krb5                      1.19.3               hf9b2bbe_0    conda-forge
lame                      3.100             h27ca646_1001    conda-forge
lcms2                     2.12                 had6a04f_0    conda-forge
lerc                      3.0                  hbdafb3b_0    conda-forge
libaec                    1.0.6                hbdafb3b_0    conda-forge
libavif                   0.10.1               h1c322ee_0    conda-forge
libblas                   3.9.0           14_osxarm64_openblas    conda-forge
libbrotlicommon           1.0.9                h1c322ee_7    conda-forge
libbrotlidec              1.0.9                h1c322ee_7    conda-forge
libbrotlienc              1.0.9                h1c322ee_7    conda-forge
libcblas                  3.9.0           14_osxarm64_openblas    conda-forge
libclang                  14.0.4          default_h81a5282_0    conda-forge
libclang13                14.0.4          default_he70ec0d_0    conda-forge
libcurl                   7.83.1               h2fcd78c_0    conda-forge
libcxx                    14.0.4               h6a5c8ee_0    conda-forge
libdeflate                1.10                 h3422bc3_0    conda-forge
libedit                   3.1.20191231         hc8eb9b7_2    conda-forge
libev                     4.33                 h642e427_1    conda-forge
libffi                    3.4.2                h3422bc3_5    conda-forge
libgfortran               5.0.0.dev0      11_0_1_hf114ba7_23    conda-forge
libgfortran5              11.0.1.dev0         hf114ba7_23    conda-forge
libglib                   2.70.2               h67e64d8_4    conda-forge
libiconv                  1.16                 h642e427_0    conda-forge
libidn2                   2.3.2                h3422bc3_0    conda-forge
liblapack                 3.9.0           14_osxarm64_openblas    conda-forge
libllvm11                 11.1.0               h93073aa_3    conda-forge
libllvm14                 14.0.4               h37c5ba8_0    conda-forge
libnetcdf                 4.8.1           nompi_h96a3436_102    conda-forge
libnghttp2                1.47.0               he723fca_0    conda-forge
libogg                    1.3.4                h27ca646_1    conda-forge
libopenblas               0.3.20          openmp_h2209c59_0    conda-forge
libopus                   1.3.1                h27ca646_1    conda-forge
libpng                    1.6.37               hf7e6567_2    conda-forge
libpq                     14.3                 h8ab49ba_0    conda-forge
libsodium                 1.0.18               h27ca646_1    conda-forge
libssh2                   1.10.0               hb80f160_2    conda-forge
libtasn1                  4.18.0               he4db4b2_1    conda-forge
libtheora                 1.1.1             h3422bc3_1005    conda-forge
libtiff                   4.4.0                h2810ee2_0    conda-forge
libunistring              0.9.10               h3422bc3_0    conda-forge
libvorbis                 1.3.7                h9f76cd9_0    conda-forge
libvpx                    1.11.0               hc470f4d_3    conda-forge
libwebp                   1.2.2                h0d20362_0    conda-forge
libwebp-base              1.2.2                h3422bc3_1    conda-forge
libxcb                    1.13              h9b22ae9_1004    conda-forge
libxml2                   2.9.14               h035c1df_0    conda-forge
libxslt                   1.1.35               ha8fb468_0    conda-forge
libzip                    1.8.0                h3887732_1    conda-forge
libzlib                   1.2.12               h90dfc92_0    conda-forge
libzopfli                 1.0.3                h9f76cd9_0    conda-forge
lightgbm                  3.3.2           py310h9799b42_0    conda-forge
littleutils               0.2.2                    pypi_0    pypi
llvm-openmp               14.0.4               hd125106_0    conda-forge
llvmlite                  0.38.1          py310hbf292a2_0    conda-forge
locket                    1.0.0              pyhd8ed1ab_0    conda-forge
loguru                    0.6.0           py310hbe9552e_1    conda-forge
lspopt                    1.1.1                    pypi_0    pypi
lxml                      4.9.0           py310h02f21da_0    conda-forge
lz4-c                     1.9.3                hbdafb3b_1    conda-forge
markupsafe                2.1.1           py310hf8d0d8f_1    conda-forge
matplotlib                3.5.2           py310hb6292c7_0    conda-forge
matplotlib-base           3.5.2           py310hbeb1b0d_0    conda-forge
matplotlib-inline         0.1.3              pyhd8ed1ab_0    conda-forge
mffpy                     0.7.3              pyhd8ed1ab_0    conda-forge
mistune                   0.8.4           py310he2143c4_1005    conda-forge
mne                       1.0.3                hd8ed1ab_1    conda-forge
mne-base                  1.0.3              pyhd8ed1ab_1    conda-forge
mne-qt-browser            0.3.1           py310hbe9552e_0    conda-forge
munkres                   1.1.4              pyh9f0ad1d_0    conda-forge
mysql-common              8.0.29               haa90c7b_1    conda-forge
mysql-libs                8.0.29               h0a1dba2_1    conda-forge
nbclient                  0.5.13             pyhd8ed1ab_0    conda-forge
nbconvert                 6.4.5           py310hbe9552e_0    conda-forge
nbformat                  5.4.0              pyhd8ed1ab_0    conda-forge
ncurses                   6.3                  h07bb92c_1    conda-forge
nest-asyncio              1.5.5              pyhd8ed1ab_0    conda-forge
nettle                    3.7                  hc6a1b29_0    conda-forge
networkx                  2.8.3              pyhd8ed1ab_0    conda-forge
nibabel                   3.2.2              pyhd8ed1ab_0    conda-forge
nilearn                   0.9.1              pyhd8ed1ab_0    conda-forge
notebook                  6.4.11             pyha770c72_0    conda-forge
nspr                      4.32                 hbdafb3b_1    conda-forge
nss                       3.78                 h1483a63_0    conda-forge
numba                     0.55.1          py310ha67b2a8_1    conda-forge
numexpr                   2.8.0           py310h3a37f5e_2    conda-forge
numpy                     1.21.6          py310h2e04ed8_0    conda-forge
openh264                  2.1.1                habe5f53_0    conda-forge
openjpeg                  2.4.0                h062765e_1    conda-forge
openssl                   1.1.1o               ha287fd2_0    conda-forge
outdated                  0.2.1                    pypi_0    pypi
packaging                 21.3               pyhd8ed1ab_0    conda-forge
pandas                    1.4.2           py310ha6a5cd6_2    conda-forge
pandocfilters             1.5.0              pyhd8ed1ab_0    conda-forge
parso                     0.8.3              pyhd8ed1ab_0    conda-forge
partd                     1.2.0              pyhd8ed1ab_0    conda-forge
patsy                     0.5.2              pyhd8ed1ab_0    conda-forge
pcre                      8.45                 hbdafb3b_0    conda-forge
pexpect                   4.8.0              pyh9f0ad1d_2    conda-forge
pickleshare               0.7.5                   py_1003    conda-forge
pillow                    9.1.1           py310hc9df86f_1    conda-forge
pip                       22.1.2             pyhd8ed1ab_0    conda-forge
pooch                     1.6.0              pyhd8ed1ab_0    conda-forge
proj                      9.0.0                hb719e4a_1    conda-forge
prometheus_client         0.14.1             pyhd8ed1ab_0    conda-forge
prompt-toolkit            3.0.29             pyha770c72_0    conda-forge
prompt_toolkit            3.0.29               hd8ed1ab_0    conda-forge
psutil                    5.9.1           py310h02f21da_0    conda-forge
pthread-stubs             0.4               h27ca646_1001    conda-forge
ptyprocess                0.7.0              pyhd3deb0d_0    conda-forge
pugixml                   1.11.4               hbdafb3b_0    conda-forge
pure_eval                 0.2.2              pyhd8ed1ab_0    conda-forge
pycparser                 2.21               pyhd8ed1ab_0    conda-forge
pydicom                   2.3.0              pyh6c4a22f_0    conda-forge
pygments                  2.12.0             pyhd8ed1ab_0    conda-forge
pymatreader               0.0.30             pyhd8ed1ab_0    conda-forge
pyopengl                  3.1.6              pyhd8ed1ab_1    conda-forge
pyopenssl                 22.0.0             pyhd8ed1ab_0    conda-forge
pyparsing                 3.0.9              pyhd8ed1ab_0    conda-forge
pyqt                      5.15.4          py310h8775411_1    conda-forge
pyqt5-sip                 12.9.0                   pypi_0    pypi
pyqtgraph                 0.12.4             pyhd8ed1ab_0    conda-forge
pyriemann                 0.2.7                    pypi_0    pypi
pyrsistent                0.18.1          py310hf8d0d8f_1    conda-forge
pysocks                   1.7.1           py310hbe9552e_5    conda-forge
pytables                  3.7.0           py310hcb00eea_0    conda-forge
python                    3.10.4          hfc7342c_0_cpython    conda-forge
python-dateutil           2.8.2              pyhd8ed1ab_0    conda-forge
python-fastjsonschema     2.15.3             pyhd8ed1ab_0    conda-forge
python-picard             0.7                pyh8a188c0_0    conda-forge
python_abi                3.10                    2_cp310    conda-forge
pytz                      2022.1             pyhd8ed1ab_0    conda-forge
pyvista                   0.34.0             pyhd8ed1ab_0    conda-forge
pyvistaqt                 0.9.0              pyhd8ed1ab_0    conda-forge
pywavelets                1.3.0           py310hdaceac9_1    conda-forge
pyyaml                    6.0             py310hf8d0d8f_4    conda-forge
pyzmq                     23.1.0          py310hede2015_0    conda-forge
qdarkstyle                3.1                pyhd8ed1ab_0    conda-forge
qt-main                   5.15.3               haf604a7_2    conda-forge
qtpy                      2.1.0              pyhd8ed1ab_0    conda-forge
readline                  8.1                  hedafd6a_0    conda-forge
requests                  2.27.1             pyhd8ed1ab_0    conda-forge
scikit-image              0.19.2          py310hdead3df_0    conda-forge
scikit-learn              1.1.1           py310h16bc539_0    conda-forge
scipy                     1.8.1           py310hdb41229_0    conda-forge
scooby                    0.5.12             pyhd8ed1ab_0    conda-forge
seaborn                   0.11.2               hd8ed1ab_0    conda-forge
seaborn-base              0.11.2             pyhd8ed1ab_0    conda-forge
send2trash                1.8.0              pyhd8ed1ab_0    conda-forge
setuptools                62.3.2          py310hbe9552e_0    conda-forge
sip                       6.5.1           py310h1b49c16_2    conda-forge
six                       1.16.0             pyh6c4a22f_0    conda-forge
snappy                    1.1.9                h39c3846_1    conda-forge
soupsieve                 2.3.1              pyhd8ed1ab_0    conda-forge
sqlite                    3.38.5               h40dfcc0_0    conda-forge
stack_data                0.2.0              pyhd8ed1ab_0    conda-forge
statsmodels               0.13.2          py310h949c51b_0    conda-forge
stochastic                0.6.0                    pypi_0    pypi
svt-av1                   1.1.0                hbe31e94_1    conda-forge
tbb                       2021.5.0             h3e96240_1    conda-forge
tbb-devel                 2021.5.0             h3e96240_1    conda-forge
tensorpac                 0.6.5                    pypi_0    pypi
terminado                 0.15.0          py310hbe9552e_0    conda-forge
testpath                  0.6.0              pyhd8ed1ab_0    conda-forge
threadpoolctl             3.1.0              pyh8a188c0_0    conda-forge
tifffile                  2022.5.4           pyhd8ed1ab_0    conda-forge
tk                        8.6.12               he1e0b03_0    conda-forge
toml                      0.10.2             pyhd8ed1ab_0    conda-forge
toolz                     0.11.2             pyhd8ed1ab_0    conda-forge
tornado                   6.1             py310hf8d0d8f_3    conda-forge
tqdm                      4.64.0             pyhd8ed1ab_0    conda-forge
traitlets                 5.2.2.post1        pyhd8ed1ab_0    conda-forge
typing_extensions         4.2.0              pyha770c72_1    conda-forge
tzdata                    2022a                h191b570_0    conda-forge
unicodedata2              14.0.0          py310hf8d0d8f_1    conda-forge
urllib3                   1.26.9             pyhd8ed1ab_0    conda-forge
utfcpp                    3.2.1                hce30654_0    conda-forge
vtk                       9.1.0           qt_py310hce58b2a_209    conda-forge
wcwidth                   0.2.5              pyh9f0ad1d_2    conda-forge
webencodings              0.5.1                      py_1    conda-forge
wheel                     0.37.1             pyhd8ed1ab_0    conda-forge
widgetsnbextension        3.6.0           py310hbe9552e_0    conda-forge
wrapt                     1.14.1          py310h02f21da_0    conda-forge
x264                      1!161.3030           h3422bc3_1    conda-forge
x265                      3.5                  hbc6ce65_3    conda-forge
xlrd                      2.0.1              pyhd8ed1ab_3    conda-forge
xmltodict                 0.13.0             pyhd8ed1ab_0    conda-forge
xorg-libxau               1.0.9                h27ca646_0    conda-forge
xorg-libxdmcp             1.1.3                h27ca646_0    conda-forge
xz                        5.2.5                h642e427_1    conda-forge
yaml                      0.2.5                h3422bc3_2    conda-forge
yasa                      0.6.1                    pypi_0    pypi
zeromq                    4.3.4                hbdafb3b_1    conda-forge
zfp                       0.5.5                hcfdfaf5_8    conda-forge
zipp                      3.8.0              pyhd8ed1ab_0    conda-forge
zlib                      1.2.12               h90dfc92_0    conda-forge
zlib-ng                   2.0.6                he4db4b2_0    conda-forge
zstd                      1.5.2                hd705a24_1    conda-forge

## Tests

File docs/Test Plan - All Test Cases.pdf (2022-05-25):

# Test Plan v0.1

Test ID | Test Case Name
1 | Verify small signal amplification through amplifier stages.
2 | Verify frequency response through filter/amplifier stages.
3 | Verify bias removal from reference probe.
4 | Verify visible muscular and brain waves through scope.
5 | Verify ADC sampling.
6 | Test input impedance of probes using a known working system.
7 | Verify the sound notification component.
8 | Verify the detection of contact by the device.
9 | Verify detection of brain waves, sleep stages, and accumulation of sleep from recorded data.
10 | Verify device records detected brainwaves during a session.
11 | Verify charging of battery via micro usb connection.
12 | Verify case water resistance.
1b | Verify detection of contact and initial brainwaves after the device is attached to the head.
2b | Verify detection of sleep stage accumulation and user wakeup.
3b | Verify device powers down on loss of head contact.
4b | Verify battrey life requirements.

Test Author: Julia Filipchuk | Test ID: | 1
Test Case Name: Verify small signal amplification through amplifier stages. | Type: | White Box
Description: Generate a small intensity signal to test the amplification range
of the device circuits. We will use a function generator in combination with a voltage divider to generate peak to peak signals of ~1uV and ~20uV. Check amplification is 23 after AD620 stage, 598 (23*26) after stage 1, and 15548 (23*26*26) after stage 2 filter/amplifier.
[' 1.0μ', expect, ' 23.0μ', ' 0.598m', ' 15.5m']
[' 20.0μ', expect, ' 0.46m', ' 12.0m', ' 311.0m']

Black Box

Tester Name: | Date:
| HW/SW Version: Breadboard/Solder | | Time:
| | Test Setup: Device with function generator connected to attenuated input. Function generator outputing a sin wave at 30 Hz. Scope available for signal verificaiton. Power supply for board power.
Step | Action | Expected Result | Pass | Fail | Comments
1 Enable power to board. | Check supplied current is reasonable.
2 Connect to attenuated input 1. | N/A
3 Measure output of AD620. | Expect ~23μV peak-to-peak signal strength.
4 Measure output of stage 1 filter. | Expect ~598μV peak-to-peak signal strength.
5 Measure output of stage 2 filter. | Expect ~15.5mV peak-to-peak signal strength.
6 Connect to attenuated input 2. | N/A
7 Measure output of AD620. | Expect 0.46mV peak-to-peak signal strength.
8 Measure output of stage 1 filter. | Expect 12.0mV peak-to-peak signal strength.
9 Measure output of stage 2 filter. | Expect 311mV peak-to-peak signal strength.

Result:

Test Author: Julia Filipchuk | Test ID: | 2
Test Case Name: Verify frequency response through filter/amplifier stages. | Type: | White Box
Description: Generate a range of input frequencies to test frequency response. High pass cut-off frequency is 0.16Hz. Low-pass cut-off frequency is 47 Hz. Expect 0.5 of Vpp at cut-off frequencies. With two filter stages 1/sqrt(2) *1/sqrt(2) = 0.5 total attenuation. | | Black Box
Tester Name: | Date:
| HW/SW Version: Breadboard/Solder | | Time:
| | Test Setup: Device with function generateo connected to attenuated input
2. Power supply connected to board. Output voltage constant.
| | Scope at output of stage 2 filter.
Step | Action | Expected Result | Pass | Fail | Comments
1 Enable power to board. | Check supplied current is reasonable.
2 Connect to attenuated input 2. | N/A
3 Generator frequency to 47 Hz. | Output voltage is ~50% of 311mV (156mV).
4 Generator frequency to 20 Hz. | Output voltage is ~100% of 311mV..
5 Generator frequency to 0.16 Hz. | Output voltage is ~50% of 311mV (156mV).

6
7
8
9
Result:

Test Author: Julia Filipchuk | Test ID: | 3
Test Case Name: Verify bias removal from reference probe. | Type: | White Box
Description: Verify bias is removing noise via the reference probe. Use the function generator a noisy wave and mirror of that same noise. Use the noise as the reference probe. | | Black Box
Tester Name: | Date:
| HW/SW Version: Breadboard/Solder | | Time:
| | Test Setup: Device board with external power supply. Probes connected to head with earclip to bias. Output of filter stage 2 to scope. Function generator channel 2 attached to bias.
Step | Action | Expected Result | Pass | Fail | Comments
1 Disconnect earclip. | View output on scope as baseline.
2 Connect earclip. | Verify output on scope improves as noise is removed.

3
4
5
6
7
8
9
Result:
Test Author: Julia Filipchuk | Test ID: | 4
Test Case Name: Verify visible muscular and brain waves through scope. | Type: | White Box
Description: Verify visible electromyography (EMG) muscular response and electroencephalogram (EEG) brain waves through amplifier stages. | | Black Box
Tester Name: | Date:
| HW/SW Version: Breadboard/Solder | | Time:
| | Test Setup: Device board with external power supply. Probes connected to head with earclip to bias. Output of filter stage 2 to scope.
Step | Action | Expected Result | Pass | Fail | Comments
1 Verify baseline waves on scope. | Baseline should be int mV range with only low frequencies.
2 Conduct Forehead scrunch. | Notice EMG signal on the scope.
3 Conduct Forehead scrunch. | Notice EMG signal on the scope.
4 Conduct Forehead scrunch. | Notice EMG signal on the scope.

5
6
7
8
9
Result:

Test Author: Julia Filipchuk | Test ID: | 5
Test Case Name: Verify ADC sampling. | Type: | White Box
Description: We will verify sampling data correctly with the ADC. We will generate an input wave and record the sampled signal. Check the recorded signal has expected values. | | Black Box
Tester Name: | Date:
| HW/SW Version: Breadboard/Solder | | Time:
Test Setup: Beaglebone board with external power supply. Input into ADC connected to function generator. Beagle bone is recording and echoing read values to external pin.
Step | Action | Expected Result | Pass | Fail | Comments
1 Generate input sin 0-3V @ 30Hz. | N/A
2 Record 30s. | | Recording should have benn created.
3 Compare recording to input. | Recording should match input.

4
5
6
7
8
9
Result:
Test Author: Julia Filipchuk | Test ID: | 6
Test Case Name: Test input impedance of probes using a known working system. | Type: | White Box
Description: Test probes are able to measure data on a working system. We will use the OpenBCI system to verify probes are usible to record brain signals. | | Black Box
Tester Name: | Date:
| HW/SW Version: Breadboard/Solder | | Time:
| | Test Setup: Connect probes to OpenBCI system and earprobes. Probes on forehead with earclip attached.
Step | Action | Expected Result | Pass | Fail | Comments
1 Observe recording on OpeBCI system. Confirm brainwaves are detectible with probes.

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
Result:

Test Author: Julia Filipchuk | Test ID: | 7
Test Case Name: Verify the sound notification component. | Type: | White Box
Description: Use a test program to generate the range of tones we will use for the device. Confirm all are heard clearly. | | Black Box
Tester Name: | Date:
| HW/SW Version: Breadboard/Solder | | Time:
Test Setup: Device with speaker circuit connected. External power supply to board.
Step | Action | Expected Result | Pass | Fail | Comments
1 Start tone test program. | N/A
2 Wait for next tone. | Confirm contact tone plays.
3 Wait for next tone. | Confirm ready tone plays.
4 Wait for next tone. | Confirm error tone plays.
5 Wait for next tone. | Confirm disconnect tone plays.
6 Wait for next tone. | Confirm wake-up tone plays.

7
8
9
Result:
Test Author: Julia Filipchuk | Test ID: | 8
Test Case Name: Verify the detection of contact by the device. | Type: | White Box
Description: Verify detection of contact by capacitive touch to the device. Utilize a test program that plays a tone when contact is detected past a threshold. Test condition with simulated sweat as well as a clean forehead. Test for no false positives in a cloth bag. | | Black Box
Tester Name: | Date:
| HW/SW Version: Breadboard/Solder | | Time:
Test Setup:
Step | Action | Expected Result | Pass | Fail | Comments
1 Turn on device. | No tone is played after 1 minute.
2 Place device on forehead. | Device makes notification tone within 1 second.
3 Remove device. | N/A
4 Spray salt water on forehead. | N/A
5 Place device on forehead. | Device makes notification tone within 1 second.
6 Place device into bag. Shake. | No tone is played after 1 minute.

7
8
9
Result:

Test Author: Julia Filipchuk | Test ID: | 9
Test Case Name: Verify detection of brain waves, sleep stages, and accumulation of sleep from recorded data. Type: | White Box
Description: Use a recorded sleep session into our sleep stage detection
algorithm. Play into the device and expect sleep stages to match. Verify sleep stages accumulate total sleep and wake is triggered.

Black Box

Tester Name: | Date:
| HW/SW Version: Breadboard/Solder | | Time:
Test Setup:
Step | Action | Expected Result | Pass | Fail | Comments
1 Run algorithm on recorded file.
2 Before sleep data. | Brainwaves but not sleep detected. Wake detected.
3 At sleep. | Stage N1 detected.
4 At deeper sleep. | Stage N2 detected.
5 Later. | | Accumulation of N1, N2 stages trigger wake-up.

6
7
8
9
Result:
Test Author: Julia Filipchuk | Test ID: | 10
Test Case Name: Verify device records detected brainwaves during a session. | Type: | White Box
Description: Test if data recording of detected brainwaves functions. | Black Box
Tester Name: | Date:
| HW/SW Version: Breadboard/Solder | | Time:
| | Test Setup: Device must have room on SD card.
Step | Action | Expected Result | Pass | Fail | Comments
1 Connect device to head. | Hear signal device is connected.
2 Record 40 seconds. | N/A
3 Scrunch forehead 10 times. | N/A
4 Record 40 seconds. | N/A

5 Stop recording.
6 View recored file. | File should exist on SD card.
7 View data. | | Scrunches should be visible as spikes.

8
9
Result:

Test Author: Julia Filipchuk | Test ID: | 11
Test Case Name: Verify charging of battery via micro usb connection. | Type: | White Box
Description: Test if battery can be charged in the system. | Black Box
Tester Name: | Date:
| HW/SW Version: Breadboard/Solder | | Time:
Test Setup: Device.
Step | Action | Expected Result | Pass | Fail | Comments
1 Discharge battery. | Measured voltage under rated 3.6 v indicating ~10% charge.
2 Connect to power. | Battery starts charging.
3 Wait for 1h. | | No fire. Device is still on.
4 Disconnect power. | Device still on.
5 Measure battery voltage. | Measured voltage above 3.7 V indicating > 60% charge.

6
7
8
9
Result:
Test Author: Julia Filipchuk | Test ID: | 12
Test Case Name: Verify case water resistance. | Type: | White Box
Description: Place in a moist tupperware with a moisture test strip inside. Spray with a spray bottle 3x. Leave overnight. | | Black Box
Tester Name: | Date:
| HW/SW Version: Breadboard/Solder | | Time:
| | Test Setup: Case with out main board but with all external connections.
Step | Action | Expected Result | Pass | Fail | Comments
1 Place Test Strip Inside. | Test strip is unactivated (dry).
2 Close case. | No gaps on case.
3 Spray 3x with water. | N/A
4 Close in tupperware container. | N/A
5 Wait 24 hours. | N/A
6 Check if test strip has been activated. Test strip should signal that himidity was low.

7
8
9
Result:

Test Author: Julia Filipchuk | Test ID: | 1b
Test Case Name: Verify detection of contact and initial brainwaves after the device is attached to the head. Type: | White Box
Description: In order to test correct device positioning we will have a user
place the device on the forehead. Audible confirmation if in contact and brainwaves in threshold. Audible alert if contact but the brainwaves are undetectable or under threshold.

Black Box

Tester Name: | Date:
| HW/SW Version: Breadboard/Solder | | Time:
| | Test Setup: Charged device with clean probes.
Step | Action | Expected Result | Pass | Fail | Comments
1 Place on head. | | Listen for contact confimation tone within 10 seconds.
2 Wait. | | Listen for brainwave confirmation tone within 40 seconds.

3
4
5
6
7
8
9
Result:
Test Author: Julia Filipchuk | Test ID: | 2b
Test Case Name: Verify detection of sleep stage accumulation and user wakeup. | Type: | White Box
Description: Verify core functionality of device. User will take a nap with the expectation that device will take them. | | Black Box
Tester Name: | Date:
| HW/SW Version: Breadboard/Solder | | Time:
| | Test Setup: Charged device with clean probes. Second person to wake user. Tired main device user.
Step | Action | Expected Result | Pass | Fail | Comments
1 Place device on forehead. | Contact tone.
2 Device is ready. | Confirmation tone.
3 User goes to sleep. | N/A
4 Wait ~20+ minutes. | Device plays wakeup tone after ~10-20 minutes asleep.

5
6
7
8
9
Result:

Test Author: Julia Filipchuk | Test ID: | 3b
Test Case Name: Verify device powers down on loss of head contact. | Type: | White Box
Description: Check the device powers off after removing from head contact. | Black Box
Tester Name: | Date:
| HW/SW Version: Breadboard/Solder | | Time:
| | Test Setup: Connect device to head and allow it to start recording.
Step | Action | Expected Result | Pass | Fail | Comments
1 Remove device from head. | N/A
2 Verify power is off. | Power off within 30 seconds.

3
4
5
6
7
8
9
Result:
Test Author: Julia Filipchuk | Test ID: 4b
Test Case Name: Verify battrey life requirements. | Type: | White Box
Description: Run device on battery for 3 days. Using it for wake-up 6 times. | Black Box
Tester Name: | Date:
HW/SW Version: Manufactured Board in Case | Time:
Test Setup: Device in case with strap. Charge device fully. Clean electrodes.
Step | Action | Expected Result | Pass | Fail | Comments
1 Wait until sleep. | N/A
2 Place on forehead. | Device beeps within 30 seconds indicating ready.
3 Fall asleep. | | Device wakes you up in ~20 minutes from you falling asleep.
4 Place device in bag. | Device is silent.

5 Wait ~12 hours. Repeat 1-5.
6 Wait ~12 hours. Repeat 1-5.
7 Wait ~12 hours. Repeat 1-5.
8 Wait ~12 hours. Repeat 1-5.
9 Wait ~12 hours. Repeat 1-5. | Device still functions after 6 uses in 3 days.

Result:

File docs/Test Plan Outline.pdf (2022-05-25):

# Test Plan Outline

2022-05-20 | Version 0.1 | Capstone Team 23 - Trail Nap Alarm
Nick Porter, Luke Hoskam, Dang Nguyen, Julia Filipchuk, Michael Weston Industry Sponsor: Dr. Christof Teuscher Faculty Advisor: Dr. Donald Duncan

## White Box - Sub-Component Functionality

1. Verify amplification range through amplifier stages.
2. Verify frequency response through filter/amplifier stages.
3. Verify bias removal from reference probe.
4. Verify visible muscular and brain waves through scope.
5. Verify ADC sampling.
6. Test input impedance of probes using a known working system.
7. Verify the sound notification component.
8. Verify the detection of contact by the device.
9. Verify algorithmic detection of brain waves, sleep stages, and accumulation of sleep from recorded data.
10.Verify device records detected brainwaves during a session.
11. Verify charging of battery via micro usb connection.
12.Verify case water resistance.

## Black Box - Device Functionality

b1.Verify detection of contact and initial brainwaves after the device is attached to the head.
b2.Verify detection of sleep stage accumulation and user wakeup.
b3.Verify device powers down on loss of contact.
b4.Verify device runtime good for 3 days of use.

## Test Points / Inputs Needed

1. Attenuated Input into AD620 reduction of 10k times.

2. Attenuated input into AD620 reduction of 500 times.
3. Output of AD620
4. Output of Filter/Amplifier Stage 1
5. Output of Filter/Amplifier Stage 2
6. Input to ADC.

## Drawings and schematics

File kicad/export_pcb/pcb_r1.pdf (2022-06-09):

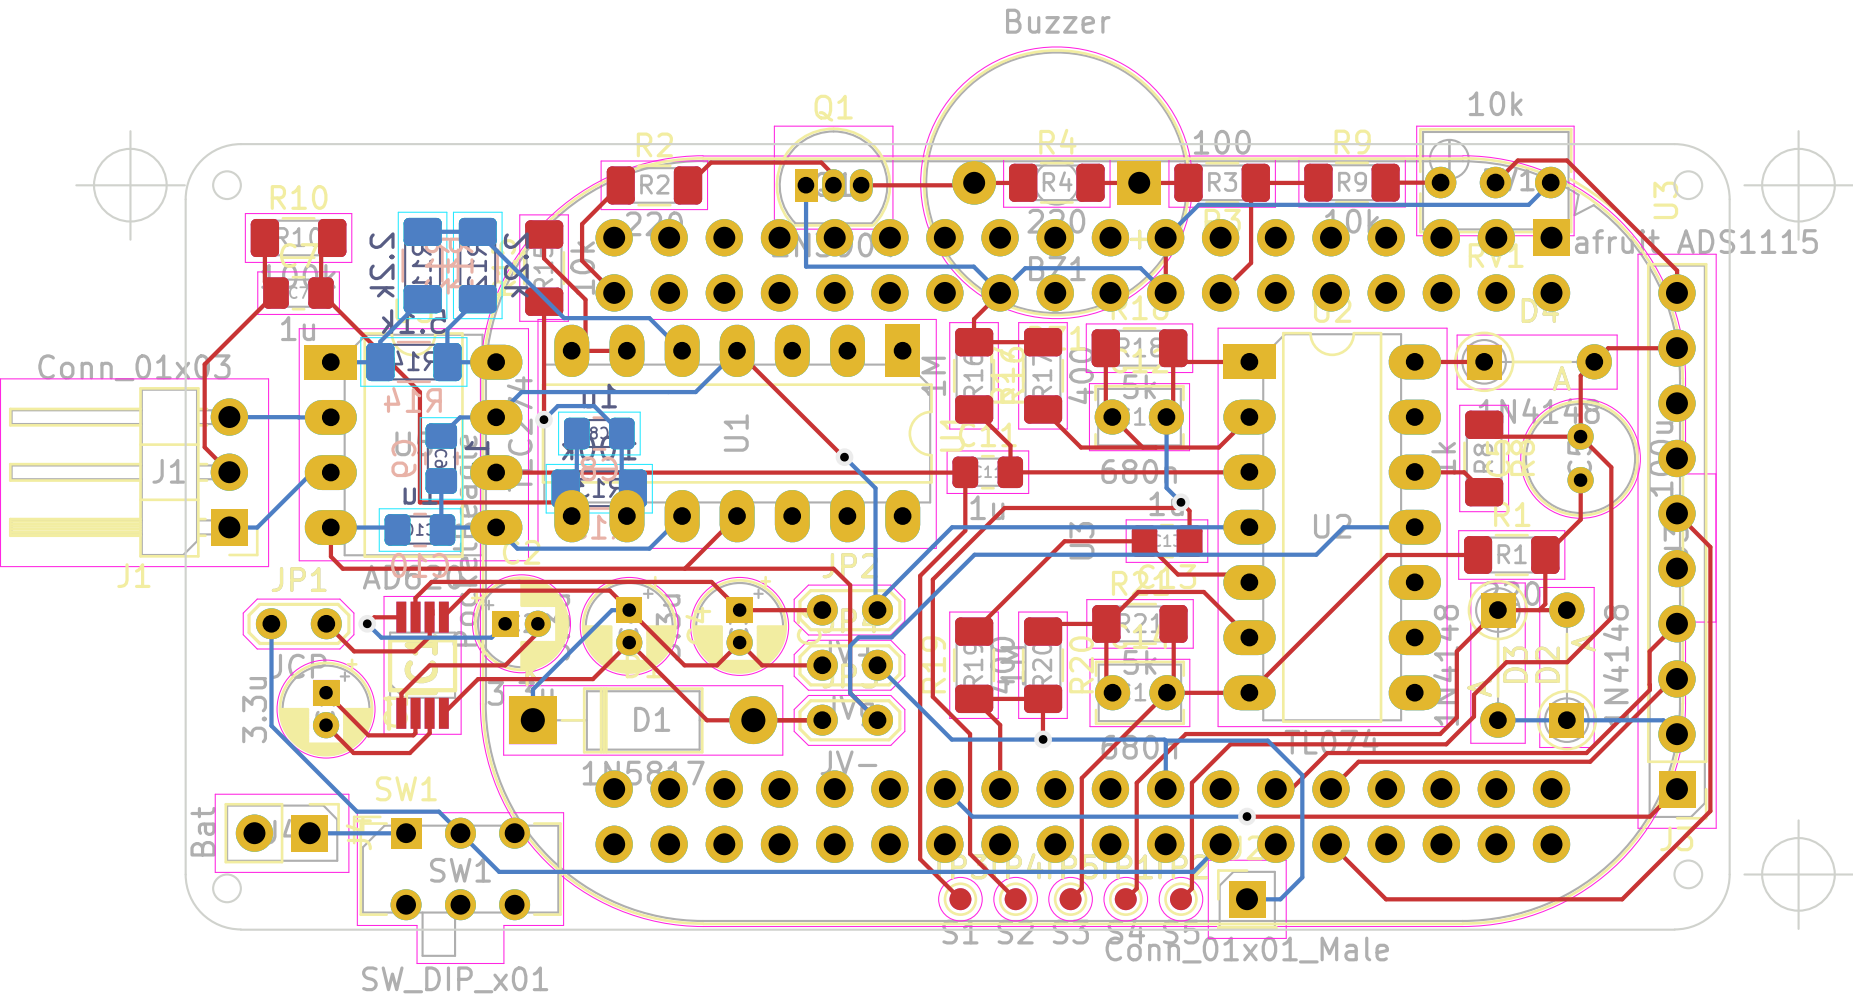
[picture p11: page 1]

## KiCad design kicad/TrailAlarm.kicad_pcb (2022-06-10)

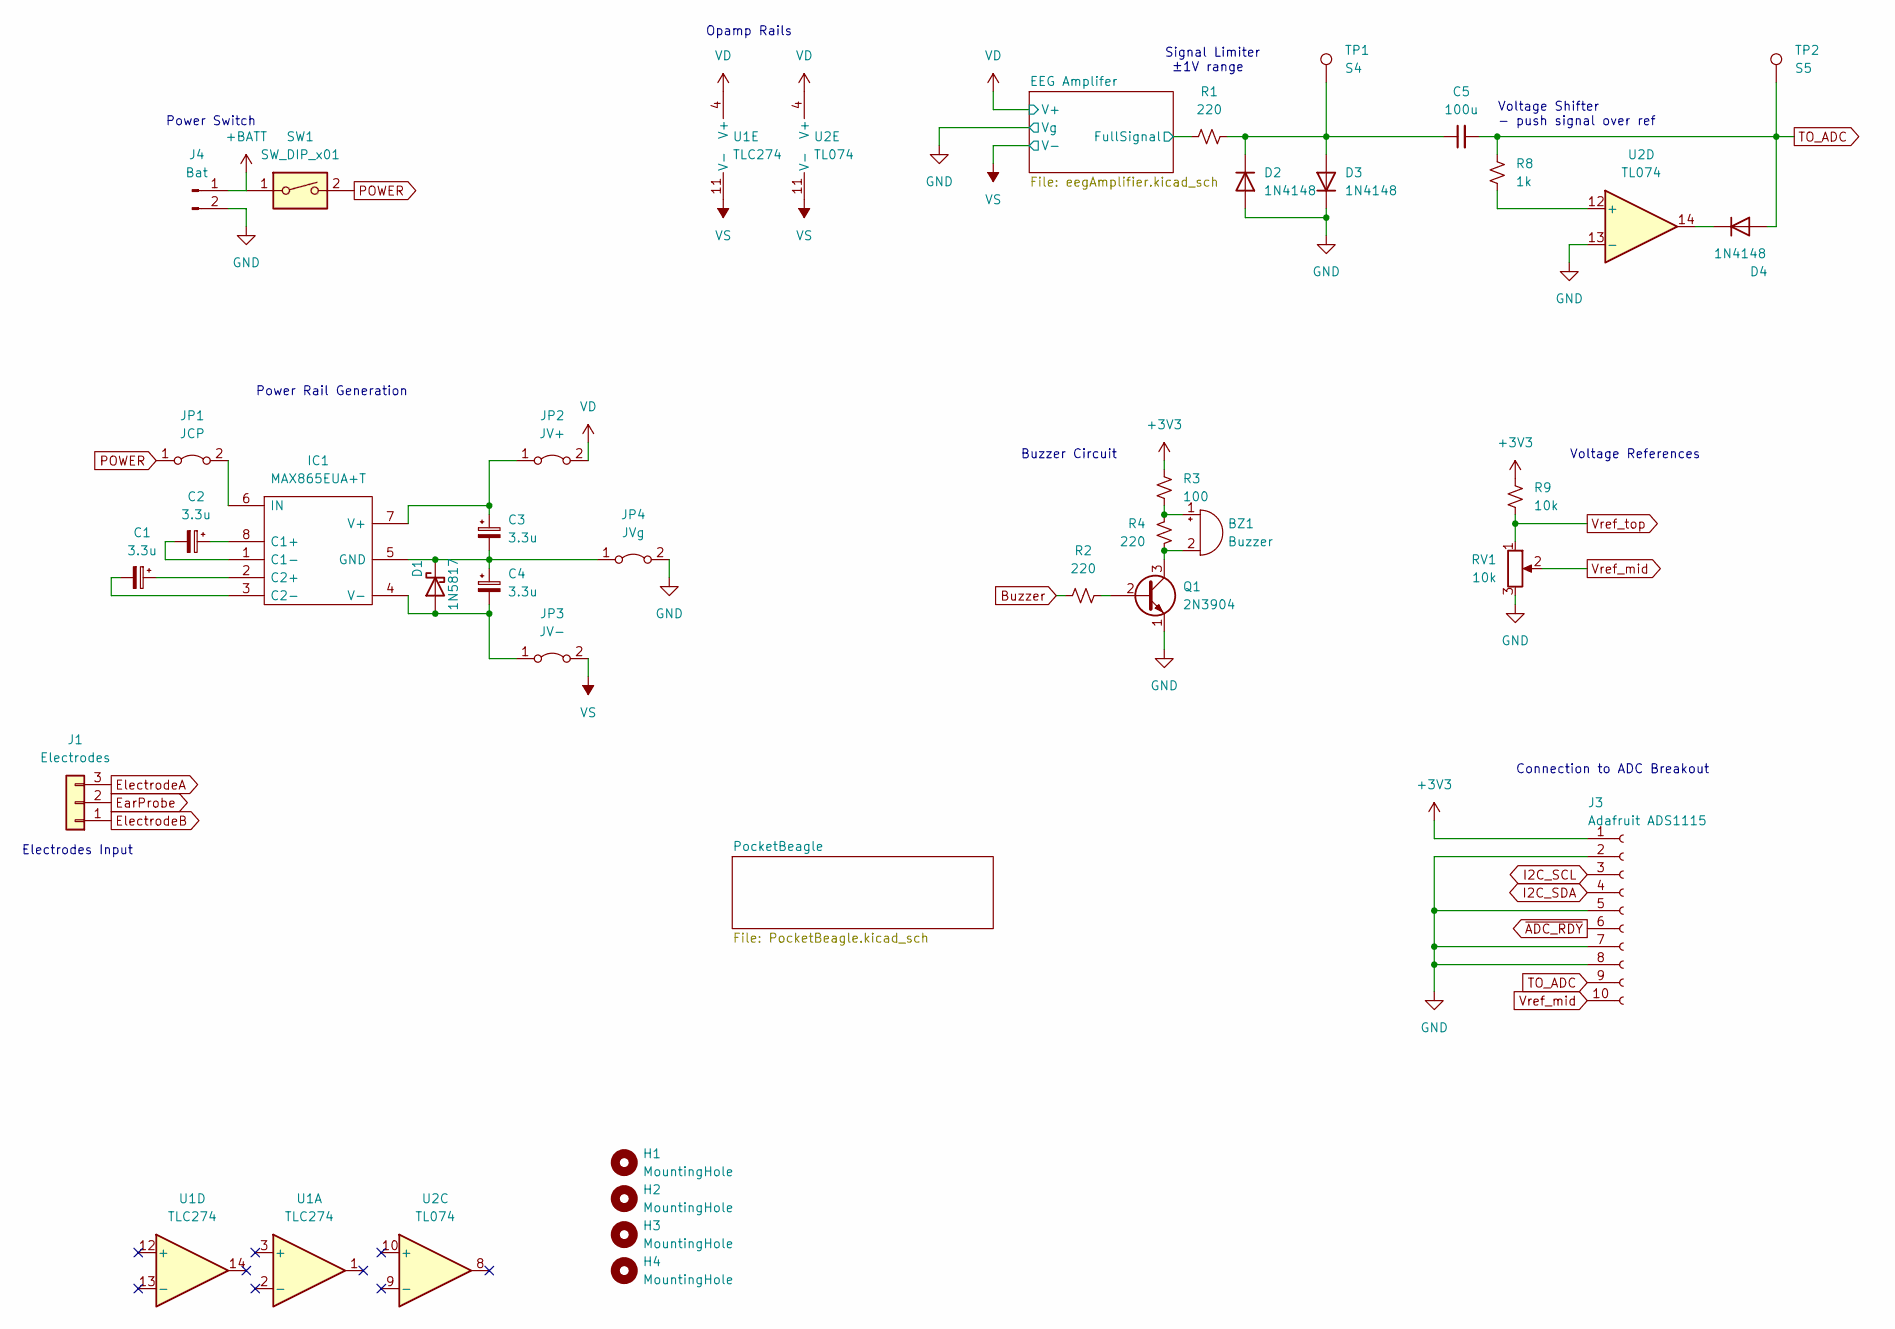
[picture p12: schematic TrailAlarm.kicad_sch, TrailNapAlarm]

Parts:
BZ1: Buzzer; Buzzer_12x9.5RM7.6
C1, C2, C3, C4: 3.3u; CP_Radial_D4.0mm_P1.50mm
C5: 100u; C_Radial_D5.0mm_H7.0mm_P2.00mm
D1: 1N5817; D_DO-41_SOD81_P10.16mm_Horizontal
D2, D3, D4: 1N4148; D_DO-35_SOD27_P5.08mm_Vertical_AnodeUp
H1, H2, H3, H4: MountingHole; MountingHole_2.2mm_M2
IC1: MAX865EUA+T; SOP65P490X111-8N; Mouser Part Number 700-MAX865EUAT
J1: Electrodes; PinHeader_1x03_P2.54mm_Horizontal
J3: Adafruit ADS1115; PinHeader_1x10_P2.54mm_Vertical
J4: Bat; PinHeader_1x02_P2.54mm_Vertical
JP1: JCP; TestPoint_2Pads_Pitch2.54mm_Drill0.8mm
JP2: JV+; TestPoint_2Pads_Pitch2.54mm_Drill0.8mm
JP3: JV-; TestPoint_2Pads_Pitch2.54mm_Drill0.8mm
JP4: JVg; TestPoint_2Pads_Pitch2.54mm_Drill0.8mm
Q1: 2N3904; TO-92_Inline
R1, R2, R4: 220; R_1206_3216Metric_Pad1.30x1.75mm_HandSolder
R3: 100; R_1206_3216Metric_Pad1.30x1.75mm_HandSolder
R8: 1k; R_1206_3216Metric_Pad1.30x1.75mm_HandSolder
R9: 10k; R_1206_3216Metric_Pad1.30x1.75mm_HandSolder
RV1: 10k; Potentiometer_Bourns_3266Y_Vertical
SW1: SW_DIP_x01; SW_CuK_JS202011AQN_DPDT_Angled
TP1: S4; TestPoint_Pad_D1.0mm
TP2: S5; TestPoint_Pad_D1.0mm
U1: TLC274; DIP-14_W7.62mm_LongPads
U2: TL074; DIP-14_W7.62mm_LongPads

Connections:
+3V3: J3.1, R3.1, R9.1; also elsewhere on the board
+BATT: J4.1, SW1.1
/EEG Amplifer/FullSignal: R1.1; also elsewhere on the board
Buzzer: R2.1; also elsewhere on the board
EarProbe: J1.2; also elsewhere on the board
ElectrodeA: J1.3; also elsewhere on the board
ElectrodeB: J1.1; also elsewhere on the board
I2C_SCL: J3.3; also elsewhere on the board
I2C_SDA: J3.4; also elsewhere on the board
unnamed: BZ1.1 (-), R3.2, R4.2
unnamed: BZ1.2 (+), Q1.3 (C), R4.1
unnamed: C1.1, IC1.2 (C2+)
unnamed: C1.2, IC1.3 (C2-)
unnamed: C2.1, IC1.8 (C1+)
unnamed: C2.2, IC1.1 (C1-)
unnamed: C3.1, IC1.7 (V+), JP2.1 (A)
unnamed: C3.2, C4.1, D1.1 (K), IC1.5 (GND), JP4.1 (A)
unnamed: C4.2, D1.2 (A), IC1.4 (V-), JP3.1 (A)
unnamed: C5.1, D2.1 (K), D3.2 (A), R1.2, TP1.1
unnamed: D4.1 (K), U2.14
unnamed: IC1.6 (IN), JP1.2 (B)
unnamed: Q1.2 (B), R2.2
unnamed: R8.2, U2.12 (+)
POWER: JP1.1 (A), SW1.2; also elsewhere on the board
TO_ADC: C5.2, D4.2 (A), J3.9, R8.1, TP2.1
VD: JP2.2 (B), U1.4 (V+), U2.4 (V+); also elsewhere on the board
VS: JP3.2 (B), U1.11 (V-), U2.11 (V-); also elsewhere on the board
Vref_mid: J3.10, RV1.2
Vref_top: R9.2, RV1.1
~ADC_RDY: J3.6; also elsewhere on the board

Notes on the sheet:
Electrodes Input
Voltage References
Signal Limiter ±1V range
Voltage Shifter - push signal over ref
Buzzer Circuit
Connection to ADC Breakout
Power Switch
Opamp Rails
Power Rail Generation

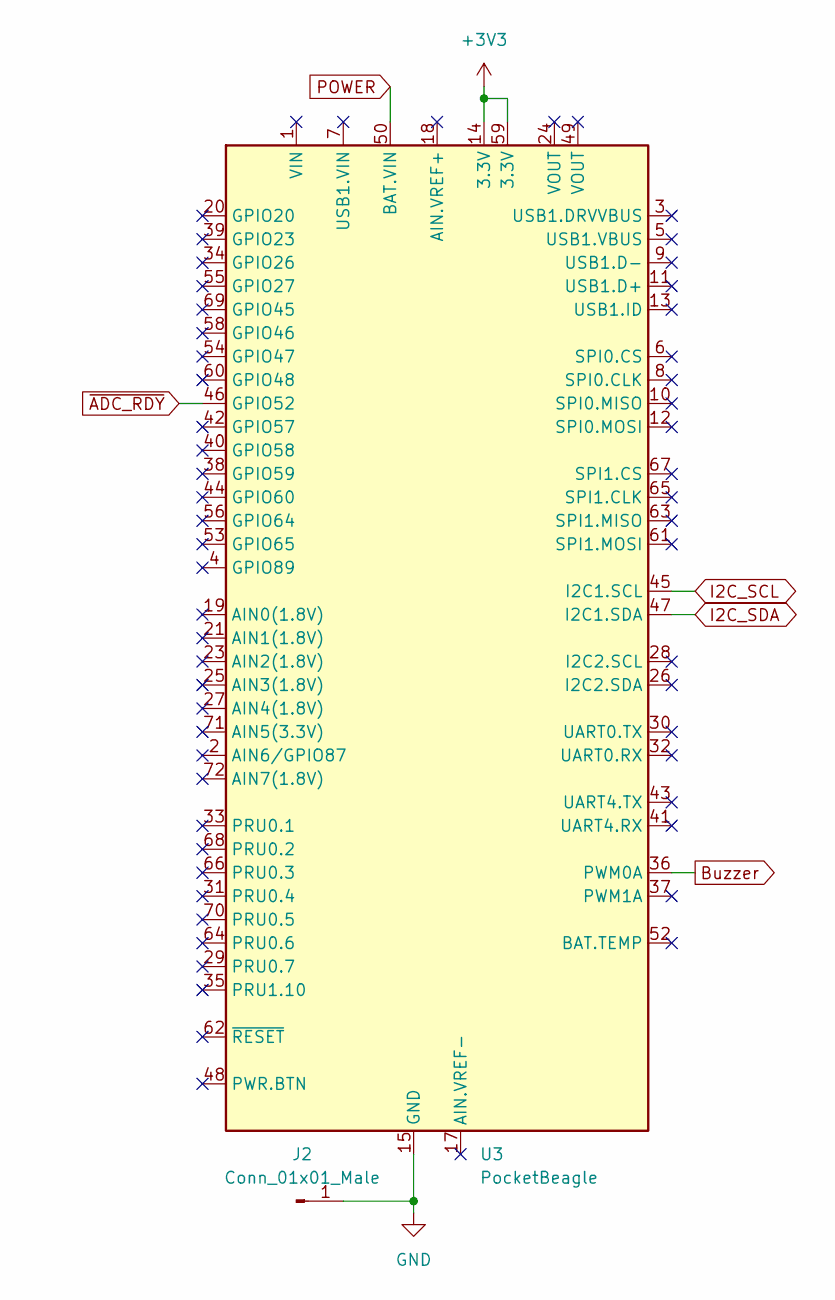
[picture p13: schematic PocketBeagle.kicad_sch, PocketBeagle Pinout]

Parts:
J2: Conn_01x01_Male; PinHeader_1x01_P2.54mm_Vertical
U3: PocketBeagle; BeagleBoard_PocketBeagle

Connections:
+3V3: U3.14 (3.3V), U3.59 (3.3V); also elsewhere on the board
Buzzer: U3.36 (PWM0A); also elsewhere on the board
I2C_SCL: U3.45 (I2C1.SCL); also elsewhere on the board
I2C_SDA: U3.47 (I2C1.SDA); also elsewhere on the board
POWER: U3.50 (BAT.VIN); also elsewhere on the board
~ADC_RDY: U3.46 (GPIO52); also elsewhere on the board

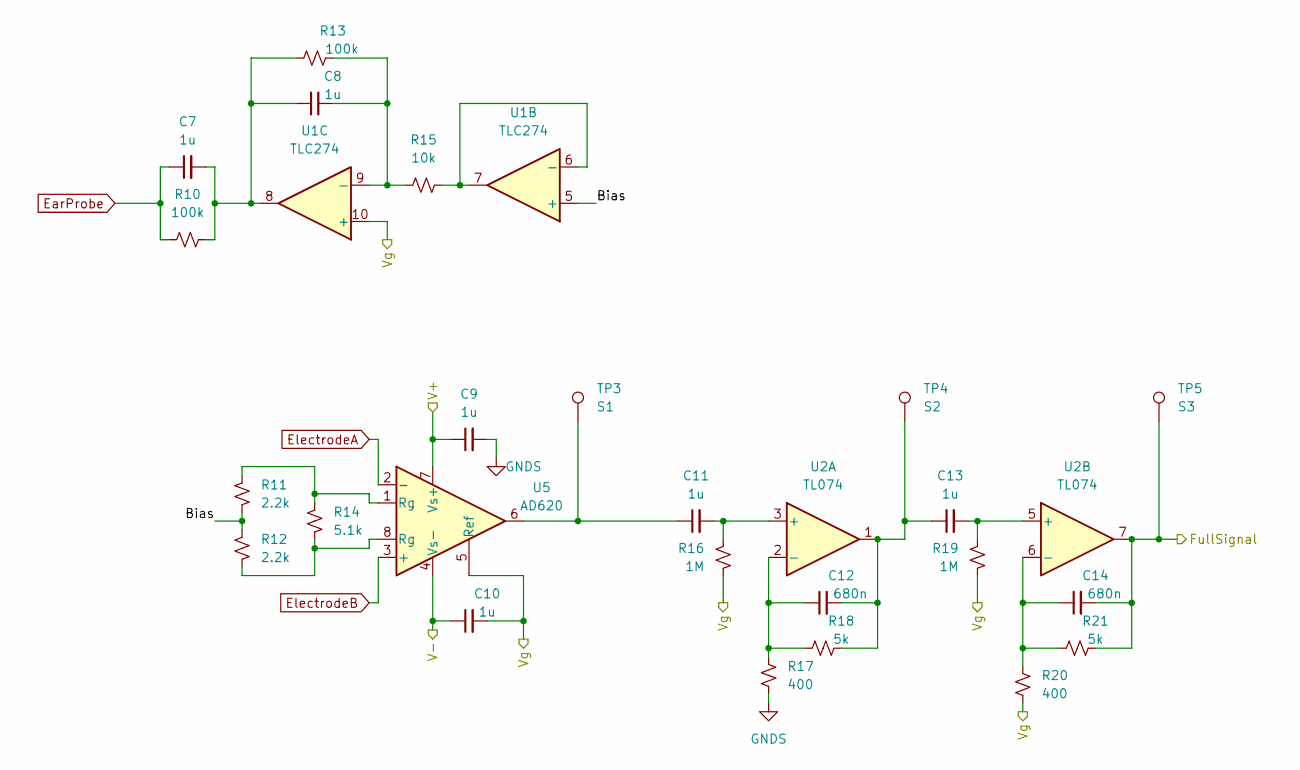
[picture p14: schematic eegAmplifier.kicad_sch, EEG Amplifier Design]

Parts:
C7, C8, C9, C10, C11, C13: 1u; C_0805_2012Metric_Pad1.18x1.45mm_HandSolder
C12, C14: 680n; C_Disc_D3.8mm_W2.6mm_P2.50mm
R10, R13: 100k; R_1206_3216Metric_Pad1.30x1.75mm_HandSolder
R11, R12: 2.2k; R_1206_3216Metric_Pad1.30x1.75mm_HandSolder
R14: 5.1k; R_1206_3216Metric_Pad1.30x1.75mm_HandSolder
R15: 10k; R_1206_3216Metric_Pad1.30x1.75mm_HandSolder
R16, R19: 1M; R_1206_3216Metric_Pad1.30x1.75mm_HandSolder
R17, R20: 400; R_1206_3216Metric_Pad1.30x1.75mm_HandSolder
R18, R21: 5k; R_1206_3216Metric_Pad1.30x1.75mm_HandSolder
TP3: S1; TestPoint_Pad_D1.0mm
TP4: S2; TestPoint_Pad_D1.0mm
TP5: S3; TestPoint_Pad_D1.0mm
U1: TLC274; DIP-14_W7.62mm_LongPads
U2: TL074; DIP-14_W7.62mm_LongPads
U5: AD620; DIP-8_W7.62mm_LongPads

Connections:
/EEG Amplifer/Bias: R11.2, R12.1, U1.5 (+)
/EEG Amplifer/FullSignal: C14.2, R21.2, TP5.1, U2.7; also elsewhere on the board
EarProbe: C7.1, R10.1; also elsewhere on the board
ElectrodeA: U5.2 (-); also elsewhere on the board
ElectrodeB: U5.3 (+); also elsewhere on the board
unnamed: C7.2, C8.1, R10.2, R13.1, U1.8
unnamed: C8.2, R13.2, R15.1, U1.9 (-)
unnamed: C11.1, TP3.1, U5.6
unnamed: C11.2, R16.2, U2.3 (+)
unnamed: C12.1, R17.1, R18.1, U2.2 (-)
unnamed: C12.2, C13.1, R18.2, TP4.1, U2.1
unnamed: C13.2, R19.2, U2.5 (+)
unnamed: C14.1, R20.1, R21.1, U2.6 (-)
unnamed: R11.1, R14.1, U5.1 (Rg)
unnamed: R12.2, R14.2, U5.8 (Rg)
unnamed: R15.2, U1.6 (-), U1.7
VD: C9.1, U5.7 (Vs+); also elsewhere on the board
VS: C10.1, U5.4 (Vs-); also elsewhere on the board

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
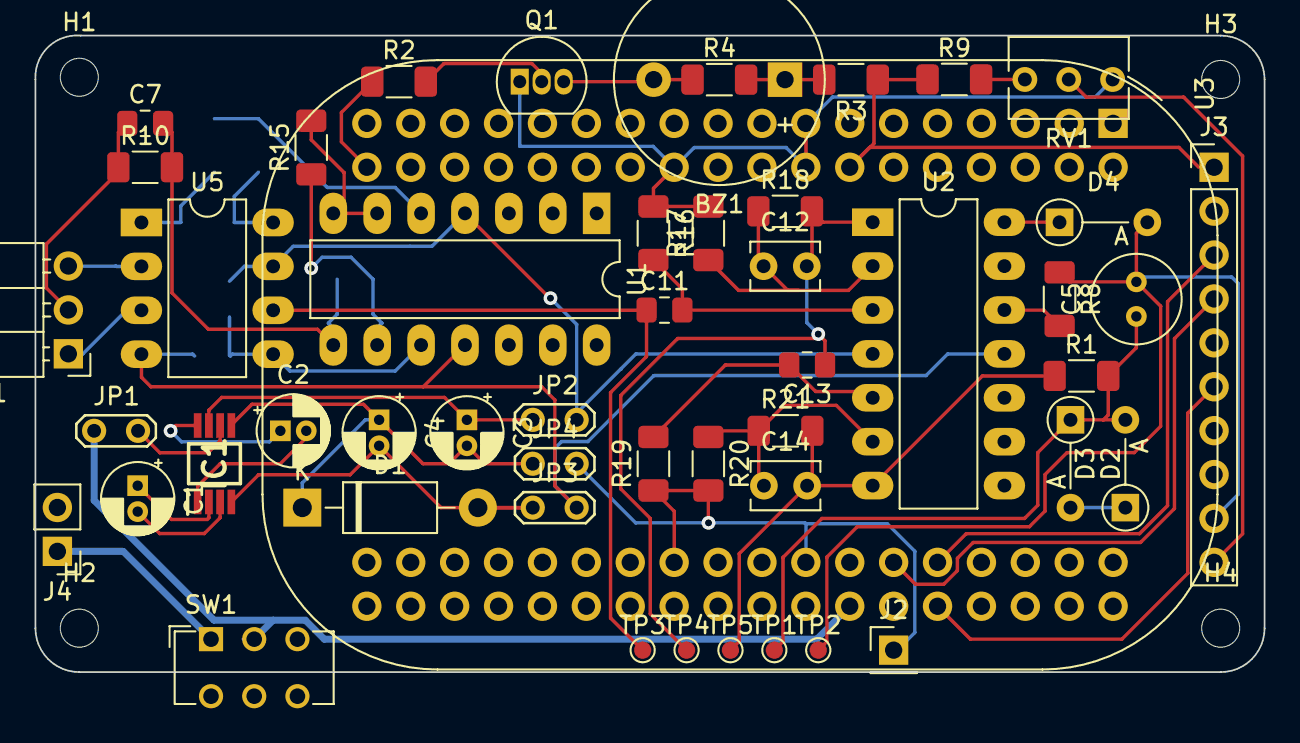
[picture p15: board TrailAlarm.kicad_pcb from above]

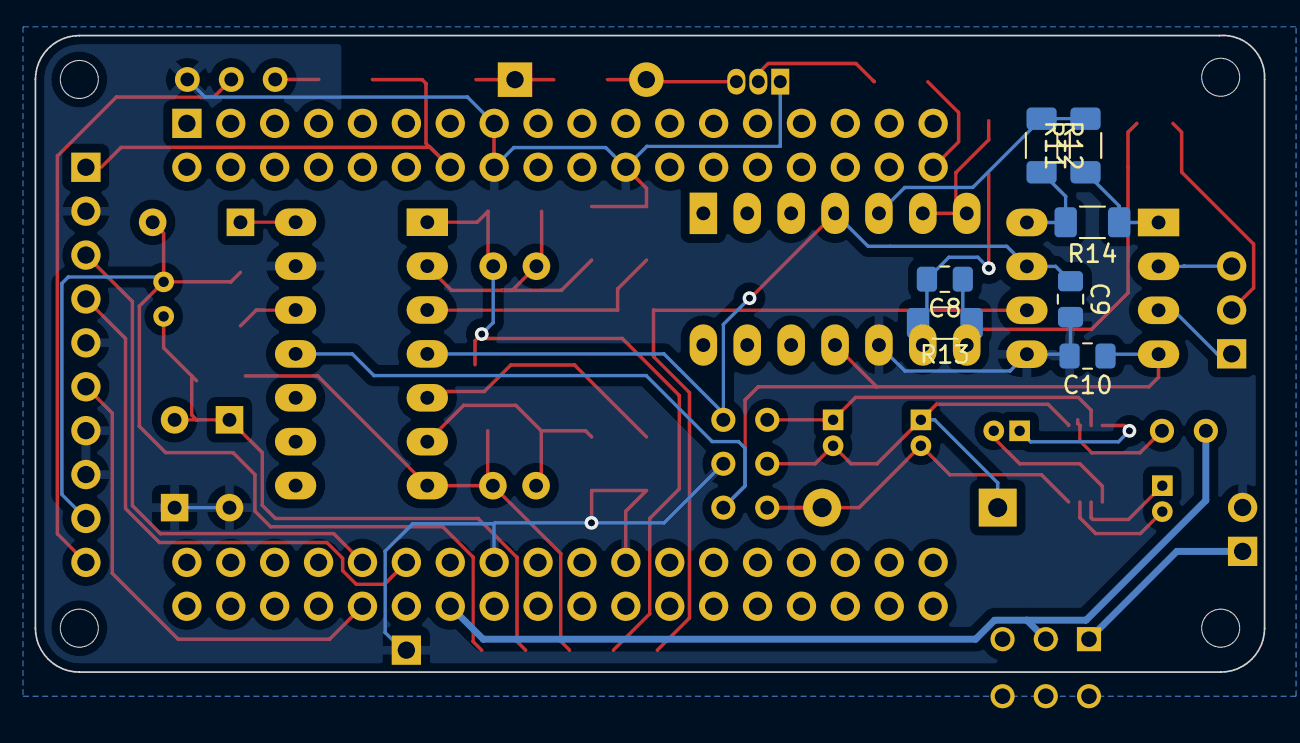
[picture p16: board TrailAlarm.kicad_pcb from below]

Board: 2 copper layers, 71.1 x 36.8 mm, 61 parts (7 on the bottom side), 43 nets.

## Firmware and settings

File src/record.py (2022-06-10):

import time, signal, os, sys
from datetime import datetime
from optparse import OptionParser
from queue import Queue

import numpy as np
from scipy.io.wavfile import write as write_wavfile

from smbus import SMBus
import Adafruit_BBIO.GPIO as GPIO

pin_alert = "P2_8" # Pin to recieve RDY interrupt from i2c ADC.
#bus = SMBus(2) # Breadboard # Select I2C bus.
bus = SMBus(1) # PCB
bounce = 0          # Bounce detection for interrupt pin.

GPIO.remove_event_detect(pin_alert)
GPIO.setup(pin_alert, GPIO.IN, pull_up_down=GPIO.PUD_UP)

def handle_signal(*args):
    print("handle_signal", *args, file=sys.stderr)
    global record
    record = False # Cancel recording. On next sample program cleanly finishes.

def handle_disconnect(*args):
    print("handle_disconnect", *args, file=sys.stderr)
    global record
    record = False # Cancel recording. On next sample program cleanly finishes.
    
signal.signal(signal.SIGINT, handle_signal)
signal.signal(signal.SIGTERM, handle_signal)
signal.signal(signal.SIGPIPE, handle_disconnect) # Check if analysis program crashes.

    
def isr_clear():
    if __debug__:
        print('isr_clr', file=sys.stderr)
    GPIO.remove_event_detect(pin_alert)
    
def isr_prime():
    if __debug__:
        print('isr_set', file=sys.stderr)
    GPIO.add_event_detect(pin_alert, GPIO.FALLING, callback=isr_handle, bouncetime=bounce)
    
def isr_handle(channel):
    # Read whenever conversion is done.
    ads1115_read()

#adc_confg = { conversion: [0xB1, 0x83], scale: (2*6.144 / 2**16) }
#adc_confg = { conversion: [0xB3 0x83], scale: (2*4.096 / 2**16) }
#adc_confg = { conversion: [0xB5 0x83], scale: (2*2.048 / 2**16) }
#adc_confg = { conversion: [0xB7, 0x83], scale: (2*1.024 / 2**16) }

class adc_config:
    # Needs 5 + 1.65 rail since bbb is at 5
    #  ±1.024 V, A2 rel A3, 128sps
    #conversion = [0b00110110, 0b10000000]
    #rate = 128
    #scale = (2*1.024 / 2**16)
    
    #  ±1.024 V, A2 rel A3, 250sps
    conversion = [0b00110110, 0b10100000]
    rate = 242
    scale = (1.024 / 2**15)

def ads1115_continuous():
    if __debug__:
        print("ads1115_continuous", file=sys.stderr)
    # Enable Interrupt first.
    isr_prime()
    
    # Enable Ready interrupt by writing MSB 1 to high threshold register and
    # writing 0 to msb1 of low threashold register.
    bus.write_i2c_block_data(0x48, 0x03, [0b10000000, 0])
    bus.write_i2c_block_data(0x48, 0x02, [0, 0])
    
    # Start Conversion of A2C
    bus.write_i2c_block_data(0x48, 0x01, adc_config.conversion)
    
    #ads1115_show_config()
    
def ads1115_show_config():
    cfg = int.from_bytes(bus.read_i2c_block_data(0x48, 0x01, 2), byteorder='big', signed=False)
    if __debug__:
        print(f"cfg: {cfg:#018b}", file=sys.stderr)
    
    ltr = int.from_bytes(bus.read_i2c_block_data(0x48, 0x02, 2), byteorder='big', signed=False)
    if __debug__:
        print(f"ltr: {ltr:#018b}", file=sys.stderr)
    htr = int.from_bytes(bus.read_i2c_block_data(0x48, 0x03, 2), byteorder='big', signed=False)
    if __debug__:
        print(f"htr: {htr:#018b}", file=sys.stderr)
    

def ads1115_poweroff():
    if __debug__:
        print("ads1115_poweroff", file=sys.stderr)
    # Disable Continuous mode by writing bit: 8 high
    bytes = adc_config.conversion.copy()
    bytes[0] |= 0x1
    bus.write_i2c_block_data(0x48, 0x01, bytes)
    #ads1115_show_config()

def ads1115_read(): # ads1115
    # Read result of conversion.
    bytes = bus.read_i2c_block_data(0x48, 0x00, 2)
    raw = int.from_bytes(bytes, byteorder='big', signed=True) # Read as int16 two's compliment
    val = raw * adc_config.scale
    
    global queue
    queue.put((raw, val, bytes))


record = True
queue = Queue(128)

# Look for next session directory in data location.
def next_session_dir():
    max_id = 0 # Next session id is this + 1.
    if os.path.isdir("../data"):
        with os.scandir("../data/") as dirs:
            for entry in dirs:
                if entry.is_dir() and entry.name.startswith("session_"):
                    id = int(entry.name.split("_")[1])
                    if id > max_id:
                        max_id = id
    return "../data/session_{:04d}".format(max_id+1)

def date_session_dir(): 
    # Build directory name with ISO 8601 format. Note: No RTC on Pocket Beagle.
    start = datetime.now()
    return "../data/{}".format(start.strftime("%Y-%m-%dT%H%M%s"))

def accumulate_start(opts = None):
    rate = adc_config.rate
    epoch = np.zeros(opts.epoch_seconds * rate, dtype=np.int16)
    epoch_i = 0
    epoch_num = 0
    path = next_session_dir()
    rate = adc_config.rate
    pipe_analysis = sys.stdout
    
    if opts.wav or opts.csv:
        os.makedirs(path, exist_ok=True)
        # Make Symlink for access to latest data. Replace existing link.
        try:
            os.unlink("../current_data")
        except FileNotFoundError:
            pass
        os.symlink(os.path.abspath(path), "../current_data", True, )
        print("Recording to '{}'".format(path), file=sys.stderr)
    
    # Enable ADC sampling in continuous mode.
    ads1115_continuous()
    start = time.time()
    
    while record:
        # Wait on samples to arrive in queue. Blocks.
        raw, val, bytes = queue.get(timeout=10)
        if raw is None:
            break
        
        # Store sample into epoch array. When full save and send to analysis.
        epoch[epoch_i] = raw
        epoch_i += 1

        if opts.show_samples and (epoch_i % (rate / 2)) == 0: # Print 2 times per second
            print("\r@ {:4} Hz : {:4d} s  {:3d} samples  {:+1.3f} V ({:+8d})".format(rate, epoch_i // rate, epoch_i, val, raw), end="", flush=True, file=sys.stderr)
        
        if epoch_i == len(epoch):
            epoch_num += 1
            epoch_i = 0
            finished = time.time()
            elapsed = finished - start
            start = finished
            print("\nEpoch {:5d} Done in {:2.3f} seconds.".format(epoch_num, elapsed), file=sys.stderr)
            
            if opts.wav:
                filename = "{}/epoch{:02}.wav".format(path, epoch_num)
                write_wavfile(filename, rate, epoch.astype(np.int16))
                print("FILE {}".format(filename), flush=True, file=pipe_analysis)
        
        if opts.num_epochs > 0 and opts.num_epochs <= epoch_num:
            # Finish recording.
            break
    
    print("DONE", flush=True, file=pipe_analysis)
        
    # Clean up
    isr_clear()
    ads1115_poweroff()


if __name__ == "__main__":
    parser = OptionParser(description='Record sampled EEG data.')
    parser.add_option('--wav', dest='wav', action='store_true', default=False,
        help="Save epoch as wav file format.")
    parser.add_option('--csv', dest='csv', action='store_true', default=False,
        help="Save epoch as csv file format. (Not Implemented)")
    parser.add_option('-s', '--seconds', dest='epoch_seconds', action='store', type='int', default=30,
        help="Number of seconds in each epoch.")
    parser.add_option('-n', '--num_epochs', dest='num_epochs', action='store', type='int', default=0,
        help="Number of epochs to record.")
    parser.add_option('-v', '--view_samples', dest='show_samples', action='store_true', default=False,
        help="Display samples at a reduced rate.")
    (opts, args) = parser.parse_args()
    accumulate_start(opts=opts)

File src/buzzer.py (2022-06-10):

import Adafruit_BBIO.PWM as PWM 
import time
import signal, os
from queue import Queue

# https://adafruit-bbio.readthedocs.io/en/latest/PWM.html
# https://pages.mtu.edu/~suits/notefreqs.html

class Note():
    C = [ 16.35, 32.70,  65.41, 130.81, 261.63, 523.25, 1046.50, 2093.00, 4186.01]
    Db= [ 17.32, 34.65,  69.30, 138.59, 277.18, 554.37, 1108.73, 2217.46, 4434.92]
    D = [ 18.35, 36.71,  73.42, 146.83, 293.66, 587.33, 1174.66, 2349.32, 4698.63]
    Eb= [ 19.45, 38.89,  77.78, 155.56, 311.13, 622.25, 1244.51, 2489.02, 4978.03]
    E = [ 20.60, 41.20,  82.41, 164.81, 329.63, 659.25, 1318.51, 2637.02, 5274.04]
    F = [ 21.83, 43.65,  87.31, 174.61, 349.23, 698.46, 1396.91, 2793.83, 5587.65]
    Gb= [ 23.12, 46.25,  92.50, 185.00, 369.99, 739.99, 1479.98, 2959.96, 5919.91]
    G = [ 24.50, 49.00,  98.00, 196.00, 392.00, 783.99, 1567.98, 3135.96, 6271.93]
    Ab= [ 25.96, 51.91, 103.83, 207.65, 415.30, 830.61, 1661.22, 3322.44, 6644.88]
    A = [ 27.50, 55.00, 110.00, 220.00, 440.00, 880.00, 1760.00, 3520.00, 7040.00]
    Bb= [ 29.14, 58.27, 116.54, 233.08, 466.16, 932.33, 1864.66, 3729.31, 7458.62]
    B = [ 30.87, 61.74, 123.47, 246.94, 493.88, 987.77, 1975.53, 3951.07, 7902.13]
    

class Buzzer():
    #pin_buzzer = "P2_1" # "EHRPWM1A" Breadboard Pin
    pin_buzzer = "P1_36" # "EHRPWM0A" Milled-board Pin

    def __init__(self):
        signal.signal(signal.SIGINT, self.cleanup) # Cleanup when closed.
        signal.signal(signal.SIGTERM, self.cleanup)
        signal.signal(signal.SIGALRM, self.tick)   # Trigger timer, alarm

        self.queue = Queue(128)
        
    def stop(self):
        signal.setitimer(signal.ITIMER_REAL, 0, 0) # Turn off Timer.
        PWM.stop(self.pin_buzzer)
        while not self.queue.empty():
            self.queue.get_nowait()

    def cleanup(self, *args):
        print("cleanup", file=sys.stderr)
        self.stop()
        PWM.cleanup()
        exit(0)
        
    def tick(self, *args):
        print("tick", file=sys.stderr)
        if self.queue.empty():
            self.stop()
        else:
            duty, hz = self.queue.get()
            PWM.start(self.pin_buzzer, duty, hz)
    
    def ready(self):
        self.queue.put((50, 261.63))
        self.queue.put(( 0,   100))
        self.queue.put((50, 440))
        signal.setitimer(signal.ITIMER_REAL, 0.02, 0.2) # Turn on Timer.

    def test(self):
        for hz in [Note.C[0], Note.C[1], Note.C[2], Note.C[3], Note.C[4], Note.C[5], Note.C[6], Note.C[7]]:
            self.queue.put((50, hz))
            self.queue.put(( 0, hz))
        signal.setitimer(signal.ITIMER_REAL, 0.02, 0.5) # Turn on Timer.


    def wake(self):
        for i in range(4):
            for hz in [Note.C[4], Note.Db[4]]:
                self.queue.put((50, hz))
                self.queue.put(( 0, hz))
        for i in range(10):
            for hz in [Note.C[5], Note.Db[5]]:
                self.queue.put((50, hz))
                self.queue.put(( 0, hz))
        signal.setitimer(signal.ITIMER_REAL, 0.02, 0.2) # Turn on Timer.
    

if __name__ == '__main__':
    import sys, os

    os.environ["PYTHONUNBUFFERED"] = "1"
    
    buzzer = Buzzer()
    for line in sys.stdin:
        cmd = line.strip().upper()
        print("Command: \"{}\"".format(cmd), file=sys.stderr)
        if cmd == "":
            pass
        elif cmd == "Q" or cmd == "DONE" or cmd == "QUIT":
            buzzer.cleanup()
        elif cmd == "S" or cmd == "STOP":
            buzzer.stop()
        elif cmd =="T" or cmd == "TEST":
            buzzer.test()
        elif cmd =="R" or cmd == "READY":
            buzzer.ready()
        elif cmd =="W" or cmd == "WAKE" or cmd == "WAKEUP":
            buzzer.wake()
    

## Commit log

2022-01-11 created a couple folders and started a readme.md
2022-04-06 added test functions for sleep stage prediction
2022-04-06 tested auto sleep scoring function on sample data
2022-05-30 added schematic
2022-05-31 Add record.py to gather sampled data into wav
2022-05-31 Added sample python code for handling python
2022-06-03 replaced image, added test fcn
    [test.py, testPlots.py]
2022-06-06 Revert "Modify analysis.py for python<3.10, test input"
    This reverts commit d812169c43bd7700fd1704d3e1cf5ce712660c43.
    [analysis.py]
2022-06-09 Add KiCad Breadboard design
    [TrailAlarm.kicad_pcb, TrailAlarm.kicad_sch, eegAmplifier.kicad_sch]
2022-06-09 Added charge pump to generate rails, switch
    [eegAmplifier.kicad_sch]
2022-06-09 Add jumpers to power rails
    [TrailAlarm.kicad_sch]
2022-06-09 Pin assignment, electrode headers
    [TrailAlarm.kicad_sch, eegAmplifier.kicad_sch]
2022-06-09 Done footprint assignment
    [TrailAlarm.kicad_sch, eegAmplifier.kicad_sch]
2022-06-09 Change buzzer pin, i2c pins, ADC plugin, ground pin.
    - Change buzzer PWM pin for easier routing.
    - Use i2c1 on P2_9(SCL) and P2_11(SDA)
    - Use ADS1115 breakout board via header
    - Add ground pin next to test points.
    - Add header for battery.
    [eegAmplifier.kicad_sch]
2022-06-09 Layout finished except test points
    [TrailAlarm.kicad_pcb]
2022-06-09 Done Layout
    - Add paths for test points, better ground plane
    [TrailAlarm.kicad_pcb]
2022-06-09 Updated schematic labels, PocketBeagle to separate sheet
    [PocketBeagle.kicad_sch, TrailAlarm.kicad_sch]
2022-06-09 Export gerber files
    - Reflow
    - print to pdf
    - generate gerber/drill files for fab
    [TrailAlarm-B_Cu.gbr, TrailAlarm-B_Mask.gbr, TrailAlarm-B_Paste.gbr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]
2022-06-10 Update src README, add source files from device
2022-06-10 Correct stopping of buzzing
    [buzzer.py]
2022-06-10 cleaned up directories
    [BoM.xlsx]
2022-06-10 Updated layout
    [PocketBeagle.kicad_sch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]
